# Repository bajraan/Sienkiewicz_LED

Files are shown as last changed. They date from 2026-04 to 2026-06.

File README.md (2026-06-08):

<p align="center" width="100%">
  
</p>

# Sienkiewicz PCB

Sienkiewicz PCB project realized in KiCAD 9

> 🔗 Project main system repository: https://github.com/bajraan/Sienkiewicz__3ART00__SYSTEM

<h1 align="center">3ART13 LED</h1>

<p align="center" width="100%">
  <a href="https://github.com/nguyen-v/KDT_Hierarchical_KiBot/actions/workflows/ci.yaml">
    
  </a>
</p>

***

<p align="center">
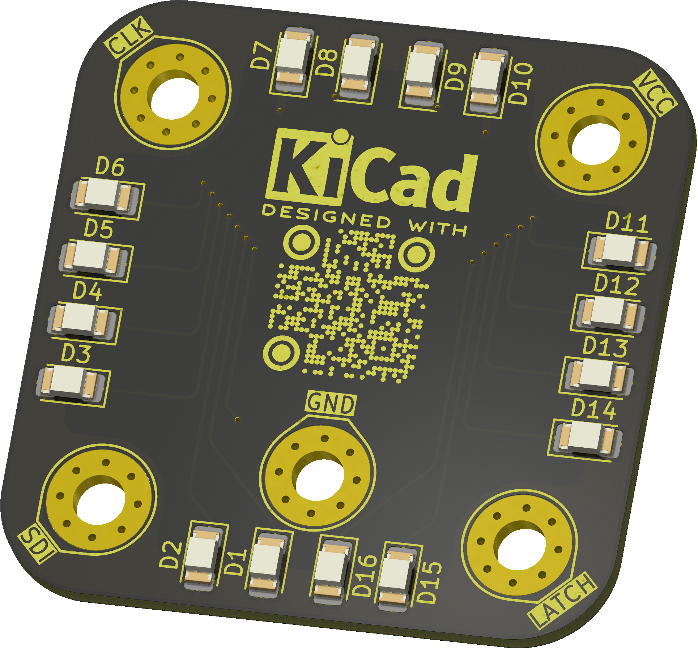
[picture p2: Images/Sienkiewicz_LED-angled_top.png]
3D Top Angled
  
&nbsp; &nbsp; &nbsp; &nbsp;
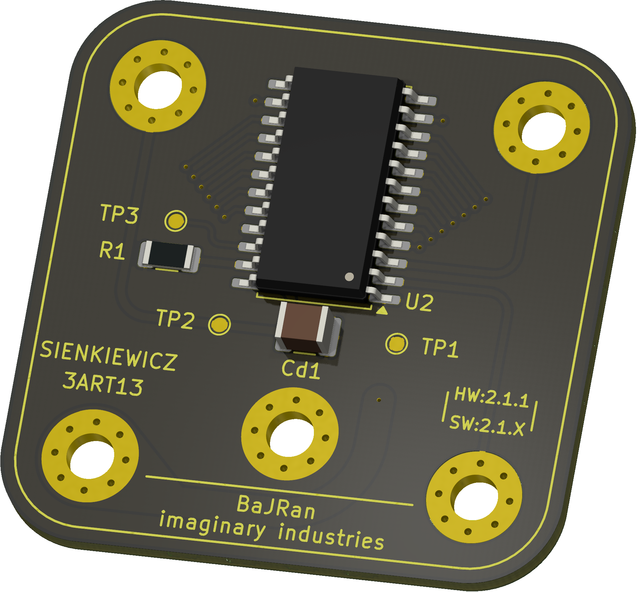
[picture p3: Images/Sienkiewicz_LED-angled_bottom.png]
3D Bottom Angled
  
</p>

***

## SPECIFICATIONS

| Parameter | Value | 
| --- | --- |
| Dimensions | 38.0 × 38.0 mm |

***

## DIRECTORY STRUCTURE

    .
    ├─ Computations       # Misc calculations
    ├─ HTML               # HTML files for generated webpage
    ├─ Images             # Pictures and renders
    │
    ├─ kibot_resources    # External resources for KiBot
    │  ├─ colors          # Color theme for KiCad
    │  ├─ fonts           # Fonts used in the project
    │  ├─ scripts         # External scripts used with KiBot
    │  └─ templates       # Templates for KiBot generated reports
    │
    ├─ kibot_yaml         # KiBot YAML config files
    ├─ KiRI               # KiRI (PCB diff viewer) files
    │
    ├─ lib                # KiCad footprint and symbol libraries
    │  ├─ 3d_models       # Component 3D models
    │  ├─ lib_fp          # Footprint libraries
    │  └─ lib_sym         # Symbol libraries
    │
    ├─ Logos              # Logos
    │
    ├─ Manufacturing      # Assembly and fabrication documents
    │  ├─ Assembly        # Assembly documents (BoM, pos, notes)
    │  │
    │  └─ Fabrication     # Fabrication documents (ZIP, notes)
    │     ├─ Drill Tables # CSV drill tables
    │     └─ Gerbers      # Gerbers
    │
    ├─ Report             # Reports for ERC/DRC
    ├─ Schematic          # PDF of schematic
    ├─ Templates          # Title block templates
    ├─ Testing
    │  └─ Testpoints      # Testpoints tables      
    │
    └─ Variants           # Outputs for assembly variants

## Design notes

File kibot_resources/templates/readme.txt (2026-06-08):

<p align="center" width="100%">
  
</p>

# Sienkiewicz PCB

Sienkiewicz PCB project realized in KiCAD 9

> 🔗 Project main system repository: https://github.com/bajraan/Sienkiewicz__3ART00__SYSTEM

<h1 align="center">${BOARD_NAME}</h1>

<p align="center" width="100%">
  <a href="${GIT_URL}/actions/workflows/ci.yaml">
    CI Badge
  </a>
</p>

***

<p align="center">
  3D Top Angled
&nbsp; &nbsp; &nbsp; &nbsp;
  3D Bottom Angled
</p>

***

## SPECIFICATIONS

| Parameter | Value | 
| --- | --- |
| Dimensions | ${bb_w_mm} × ${bb_h_mm} mm |

***

## DIRECTORY STRUCTURE

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

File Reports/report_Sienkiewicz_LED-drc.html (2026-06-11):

Logo

(https://github.com/INTI-CMNB/KiBot/) | DRC report for Sienkiewicz_LED
| PCB: Sienkiewicz_LED Revision: 2.1.1+ (Unreleased) Date: 2026-06-11T19:33:59+0000 KiCad Version: 9.0.7 | Errors: 0 Warnings: 21 Total: 21

Violations

Type | Description | Details
track_dangling | Track has unconnected end | @(149.975001 mm, 93.0 mm): Track [+5V] on B.Cu (Sig, PWR), length 3.5250 mm
lib_footprint_mismatch | Footprint 'LED_1206_3216Metric' does not match copy in library 'LED_SMD'. | @(146.5 mm, 106.0 mm): Footprint D1
lib_footprint_mismatch | Footprint 'LED_1206_3216Metric' does not match copy in library 'LED_SMD'. | @(142.5 mm, 74.0 mm): Footprint D7
lib_footprint_mismatch | Footprint 'LED_1206_3216Metric' does not match copy in library 'LED_SMD'. | @(154.5 mm, 106.0 mm): Footprint D15
lib_footprint_mismatch | Footprint 'LED_1206_3216Metric' does not match copy in library 'LED_SMD'. | @(132.5 mm, 88.0 mm): Footprint D5
lib_footprint_mismatch | Footprint 'LED_1206_3216Metric' does not match copy in library 'LED_SMD'. | @(150.5 mm, 106.0 mm): Footprint D16
lib_footprint_mismatch | Footprint 'LED_1206_3216Metric' does not match copy in library 'LED_SMD'. | @(132.5 mm, 96.0 mm): Footprint D3
lib_footprint_mismatch | Footprint 'LED_1206_3216Metric' does not match copy in library 'LED_SMD'. | @(154.5 mm, 74.0 mm): Footprint D10
lib_footprint_mismatch | Footprint 'LED_1206_3216Metric' does not match copy in library 'LED_SMD'. | @(142.5 mm, 106.0 mm): Footprint D2
lib_footprint_mismatch | Footprint 'LED_1206_3216Metric' does not match copy in library 'LED_SMD'. | @(164.5 mm, 84.0 mm): Footprint D11
lib_footprint_mismatch | Footprint 'LED_1206_3216Metric' does not match copy in library 'LED_SMD'. | @(146.5 mm, 74.0 mm): Footprint D8
lib_footprint_mismatch | Footprint 'LED_1206_3216Metric' does not match copy in library 'LED_SMD'. | @(164.5 mm, 96.0 mm): Footprint D14
lib_footprint_mismatch | Footprint 'LED_1206_3216Metric' does not match copy in library 'LED_SMD'. | @(164.5 mm, 88.0 mm): Footprint D12
lib_footprint_mismatch | Footprint 'LED_1206_3216Metric' does not match copy in library 'LED_SMD'. | @(150.5 mm, 74.0 mm): Footprint D9
lib_footprint_mismatch | Footprint 'LED_1206_3216Metric' does not match copy in library 'LED_SMD'. | @(132.5 mm, 84.0 mm): Footprint D6
lib_footprint_mismatch | Footprint 'LED_1206_3216Metric' does not match copy in library 'LED_SMD'. | @(132.5 mm, 92.0 mm): Footprint D4
lib_footprint_mismatch | Footprint 'LED_1206_3216Metric' does not match copy in library 'LED_SMD'. | @(164.5 mm, 92.0 mm): Footprint D13
lib_footprint_mismatch | Footprint 'SOIC-24W_7.5x15.4mm_P1.27mm' does not match copy in library 'Package_SO'. | @(148.5 mm, 83.0 mm): Footprint U2
lib_footprint_mismatch | Footprint 'C_1210_3225Metric' does not match copy in library 'Capacitor_SMD'. | @(148.5 mm, 93.0 mm): Footprint Cd1
lib_footprint_mismatch | Footprint 'R_1206_3216Metric' does not match copy in library 'Resistor_SMD'. | @(158.66 mm, 88.715 mm): Footprint R1

Schematic parity

Type | Description | Details
extra_footprint | Extra footprint | @(148.5 mm, 81.0 mm): Footprint REF**

Generated by KiBot (https://github.com/INTI-CMNB/KiBot/) v1.9.1

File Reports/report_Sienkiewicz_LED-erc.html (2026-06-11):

Logo

(https://github.com/INTI-CMNB/KiBot/) | ERC report for Sienkiewicz_LED
| Schematic: Sienkiewicz_LED Revision: 2.1.1+ (Unreleased) Date: 2026-06-11T19:33:57+0000 KiCad Version: 9.0.7 | Errors: 0 Warnings: 18 Total: 18

Sheet / (Sienkiewicz_LED.kicad_sch)

Type | Description | Details
footprint_link_issues | The current configuration does not include the footprint library '__Sienkiewicz'. | @(1.6002 mm, 0.7112 mm): Symbol U1 [Sienkiewicz]
lib_symbol_issues | The current configuration does not include the symbol library '__Sienkiewicz' | @(1.6002 mm, 0.7112 mm): Symbol U1 [Sienkiewicz]
lib_symbol_mismatch | Symbol 'LED_Small' doesn't match copy in library 'Device' | @(1.524 mm, 0.7112 mm): Symbol D1 [LED_Small]
lib_symbol_mismatch | Symbol 'LED_Small' doesn't match copy in library 'Device' | @(1.524 mm, 0.7366 mm): Symbol D2 [LED_Small]
lib_symbol_mismatch | Symbol 'LED_Small' doesn't match copy in library 'Device' | @(1.524 mm, 0.762 mm): Symbol D3 [LED_Small]
lib_symbol_mismatch | Symbol 'LED_Small' doesn't match copy in library 'Device' | @(1.524 mm, 0.7874 mm): Symbol D4 [LED_Small]
lib_symbol_mismatch | Symbol 'LED_Small' doesn't match copy in library 'Device' | @(1.524 mm, 0.8128 mm): Symbol D5 [LED_Small]
lib_symbol_mismatch | Symbol 'LED_Small' doesn't match copy in library 'Device' | @(1.524 mm, 0.8382 mm): Symbol D6 [LED_Small]
lib_symbol_mismatch | Symbol 'LED_Small' doesn't match copy in library 'Device' | @(1.524 mm, 0.8636 mm): Symbol D7 [LED_Small]
lib_symbol_mismatch | Symbol 'LED_Small' doesn't match copy in library 'Device' | @(1.524 mm, 0.889 mm): Symbol D8 [LED_Small]
lib_symbol_mismatch | Symbol 'LED_Small' doesn't match copy in library 'Device' | @(1.524 mm, 0.9144 mm): Symbol D9 [LED_Small]
lib_symbol_mismatch | Symbol 'LED_Small' doesn't match copy in library 'Device' | @(1.524 mm, 0.9398 mm): Symbol D10 [LED_Small]
lib_symbol_mismatch | Symbol 'LED_Small' doesn't match copy in library 'Device' | @(1.524 mm, 0.9652 mm): Symbol D11 [LED_Small]
lib_symbol_mismatch | Symbol 'LED_Small' doesn't match copy in library 'Device' | @(1.524 mm, 0.9906 mm): Symbol D12 [LED_Small]
lib_symbol_mismatch | Symbol 'LED_Small' doesn't match copy in library 'Device' | @(1.524 mm, 1.016 mm): Symbol D13 [LED_Small]
lib_symbol_mismatch | Symbol 'LED_Small' doesn't match copy in library 'Device' | @(1.524 mm, 1.0414 mm): Symbol D14 [LED_Small]
lib_symbol_mismatch | Symbol 'LED_Small' doesn't match copy in library 'Device' | @(1.524 mm, 1.0668 mm): Symbol D15 [LED_Small]
lib_symbol_mismatch | Symbol 'LED_Small' doesn't match copy in library 'Device' | @(1.524 mm, 1.0922 mm): Symbol D16 [LED_Small]

Generated by KiBot (https://github.com/INTI-CMNB/KiBot/) v1.9.1

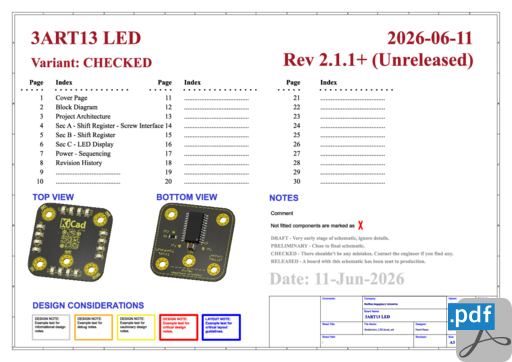
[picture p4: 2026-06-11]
HTML/images/cat_pdf_schematic_Sienkiewicz_LED-schematic.png

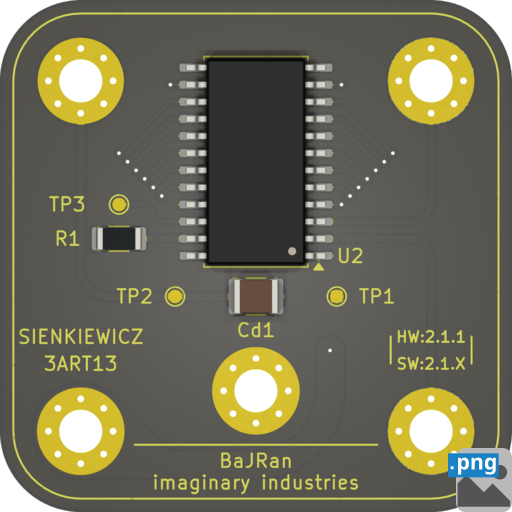
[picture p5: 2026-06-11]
HTML/images/cat_png_3d_viewer_bottom_Sienkiewicz_LED-bottom.png

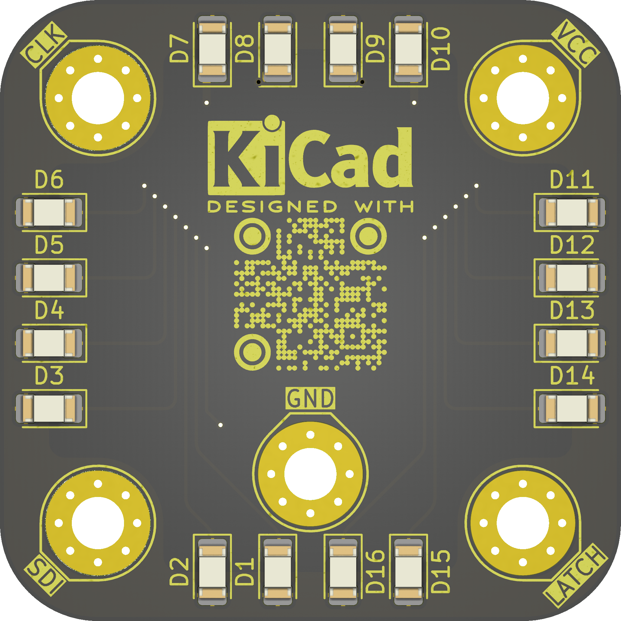
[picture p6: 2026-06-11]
Images/Sienkiewicz_LED-top.png

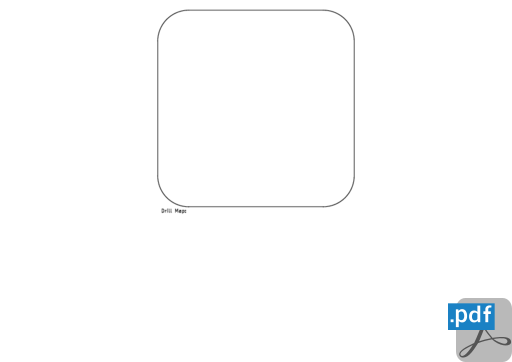
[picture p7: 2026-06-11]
HTML/images/cat_pdf_drill_map_Sienkiewicz_LED-NPTH_drill_map.png

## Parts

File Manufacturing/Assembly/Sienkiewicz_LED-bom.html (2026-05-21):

 | Bill of Materials
 | Schematic: Sienkiewicz_LED Variant: CHECKED Revision: 2.1.1+ (Unreleased) Date: 2025-01-12 KiCad Version: 9.0.7+1 | Component Groups: 5 Component Count: 20 (per PCB) Fitted Components: 20 (per PCB) Number of PCBs: 1 Total Components: 20 (for 1 PCBs)
Row | Quantity Per PCB | References | Value | Datasheet | Footprint | Description | Manufacturer | Manufacturer Part Number | Supplier Part Number
1 | 1 | Cd1 | 100nF | ~ | C_1210_3225Metric | Unpolarized capacitor, small symbol
2 | 16 | D1 D2 D3 D4 D5 D6 D7 D8 D9 D10 D11 D12 D13 D14 D15 D16 | YL | ~ | LED_1206_3216Metric | Light emitting diode, small symbol
3 | 1 | R1 | 1k5 | ~ | R_1206_3216Metric | Resistor, small symbol
4 | 1 | U1 | B-B Interface |  | Sienkiewicz
5 | 1 | U2 | STP16CP05M | https://www.st.com/resource/en/datasheet/stp16cp05.pdf | SOIC-24W_7.5x15.4mm_P1.27mm | 16-bit constant current LED sink driver, 5..100mA output current, 20V driving capability, 3.0..5.5V power supply, SOIC-24
Color reference for columns:
KiCad Fields (default)
Generated Fields
User Fields
Empty Fields

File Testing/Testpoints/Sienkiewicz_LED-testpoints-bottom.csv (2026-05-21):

Ref. | Net | X [mm] | Y [mm]
TP1 | GND | 78.50 | 13.00
TP2 | +5V | 90.50 | 13.00
TP3 | Net-(U2-SDO) | 94.66 | 19.82

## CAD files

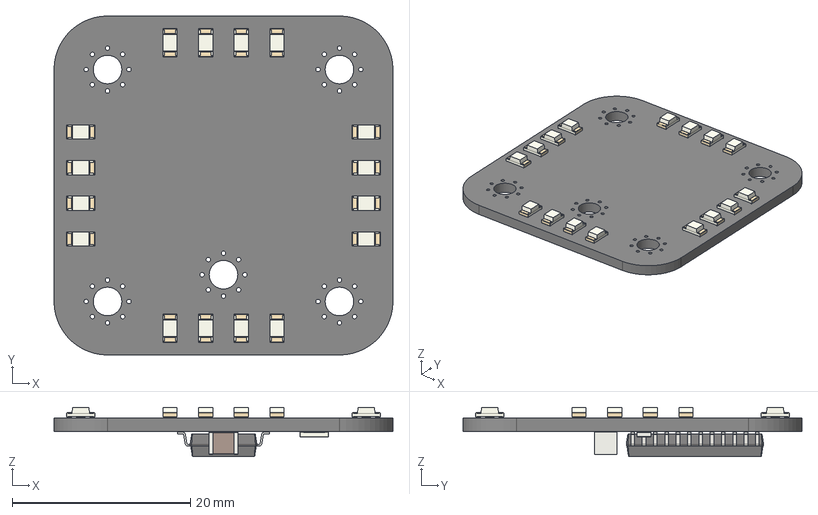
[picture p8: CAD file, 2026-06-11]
3D/Sienkiewicz_LED.step
38.0 x 38.0 x 5.52 mm
LED_1206_3216Metric x 16
SOIC-24W_7.5x15.4mm_P1.27mm
C_1210_3225Metric
R_1206_3216Metric
kibot_dib91y2s_PCB

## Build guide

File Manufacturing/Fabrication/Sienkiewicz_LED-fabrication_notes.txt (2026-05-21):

FABRICATION NOTES (UNLESS OTHERWISE SPECIFIED)

1)	FABRICATE PER IPC-6012A CLASS 2.

2)	OUTLINE DEFINED IN SEPARATE GERBER FILE WITH
	"Edge_Cuts.GBR" SUFFIX.

	DIMENSIONS OF CIRCUMSIZED RECTANGLE SHOWN ON THIS
	DRAWING FOR REFERENCE ONLY.

3)	SEE SEPARATE DRILL FILES WITH ".DRL" SUFFIX 
	FOR HOLE LOCATIONS.

	SELECTED HOLE LOCATIONS SHOWN ON THIS DRAWING 
	FOR REFERENCE ONLY.

4)	SURFACE FINISH: IMMERSION GOLD

5)	SOLDERMASK ON BOTH SIDES OF THE BOARD SHALL 
	BE LPI, COLOR BLACK.

6)	SILK SCREEN LEGEND TO BE APPLIED PER LAYER 
	STACKUP USING YELLOW NON-CONDUCTIVE EPOXY INK.

7)	ALL VIAS ARE TENTED ON BOTH SIDES UNLESS 
	SOLDERMASK OPENED IN GERBER.

8)	VENDOR SHOULD FOLLOW ROHS COMPLIANT PROCESS 
	AND Pb FREE FOR MANUFACTURING

9)	PCB MATERIAL REQUIREMENTS:

	A.	FLAMMABILITY RATING MUST MEET OR EXCEED 
		UL94V-0 REQUIREMENTS.
	B.	Tg 170 C OR EQUIVALENT.
	C.	EQUIVALENT MATERIAL SHALL BE RoHS COMPLIANT, 
		HALOGEN FREE AND APPROVED BY BAJRAN IMGAGINARY INDUSTRIES.

10)	DESIGN GEOMETRY MINIMUM FEATURE SIZES:

	BOARD SIZE				38.000 × 38.000 mm
	BOARD THICKNESS		1.610 mm
	TRACE WIDTH			0.200 mm
	TRACE TO TRACE		0.200 mm
	MIN. HOLE (PTH)			0.250 mm
	MIN. HOLE (NPTH)		N/A mm
	ANNULAR RING			0.150 mm
	COPPER TO HOLE		0.254 mm
	COPPER TO EDGE		0.250 mm
	HOLE TO HOLE			0.254 mm

11)	REFER TO IMPEDANCE TABLE FOR IMPEDANCE CONTROL REQUIREMENTS.

12)	CONFIRM SPACE WIDTHS AND SPACINGS.

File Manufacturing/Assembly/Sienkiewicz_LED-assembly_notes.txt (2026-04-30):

ASSEMBLY NOTES (UNLESS OTHERWISE SPECIFIED)

1)	DO NOT POPULATE PARTS ARE MARKED WITH A RED CROSS.

2)	DO NOT POPULATE PARTS ARE NOT PRESENT IN THE BOM.

3)	IF CONFLICTING INFORMATION IS FOUND BETWEEN THE ASSEMBLY
	FILE AND BOM, BOM SHOULD BE USED AS THE MAIN SOURCE.

4)	CONFORMAL COATING IS NOT REQUIRED.

5)	DOT IDENTIFIES PIN #1 LOCATION AND DEVICE ORIENTATION
	WHEN VIEWED FROM THE TOP.

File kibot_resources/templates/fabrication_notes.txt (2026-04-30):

FABRICATION NOTES (UNLESS OTHERWISE SPECIFIED)

1)	FABRICATE PER IPC-6012A CLASS 2.

2)	OUTLINE DEFINED IN SEPARATE GERBER FILE WITH
	"Edge_Cuts.GBR" SUFFIX.

	DIMENSIONS OF CIRCUMSIZED RECTANGLE SHOWN ON THIS
	DRAWING FOR REFERENCE ONLY.

3)	SEE SEPARATE DRILL FILES WITH ".DRL" SUFFIX 
	FOR HOLE LOCATIONS.

	SELECTED HOLE LOCATIONS SHOWN ON THIS DRAWING 
	FOR REFERENCE ONLY.

4)	SURFACE FINISH: ${pcb_finish_cap}

5)	SOLDERMASK ON BOTH SIDES OF THE BOARD SHALL 
	BE LPI, COLOR ${solder_mask_color_text_cap}.

6)	SILK SCREEN LEGEND TO BE APPLIED PER LAYER 
	STACKUP USING ${silk_screen_color_text_cap} NON-CONDUCTIVE EPOXY INK.

7)	ALL VIAS ARE TENTED ON BOTH SIDES UNLESS 
	SOLDERMASK OPENED IN GERBER.

8)	VENDOR SHOULD FOLLOW ROHS COMPLIANT PROCESS 
	AND Pb FREE FOR MANUFACTURING

9)	PCB MATERIAL REQUIREMENTS:

	A.	FLAMMABILITY RATING MUST MEET OR EXCEED 
		UL94V-0 REQUIREMENTS.
	B.	Tg 170 C OR EQUIVALENT.
	C.	EQUIVALENT MATERIAL SHALL BE RoHS COMPLIANT, 
		HALOGEN FREE AND APPROVED BY ${COMPANY_cap}.

10)	DESIGN GEOMETRY MINIMUM FEATURE SIZES:

	BOARD SIZE				${bb_w_mm} × ${bb_h_mm} mm
	BOARD THICKNESS		${thickness_mm} mm
	TRACE WIDTH			${track_mm} mm
	TRACE TO TRACE		${clearance_mm} mm
	MIN. HOLE (PTH)			${drill_pth_real_mm} mm
	MIN. HOLE (NPTH)		${drill_npth_real_mm} mm
	ANNULAR RING			${oar_mm} mm
	COPPER TO HOLE		${c2h_mm} mm
	COPPER TO EDGE		${c2e_mm} mm
	HOLE TO HOLE			${h2h_mm} mm
#?stackup and impedance_controlled

#?stackup and impedance_controlled
11)	REFER TO IMPEDANCE TABLE FOR IMPEDANCE CONTROL REQUIREMENTS.
#?stackup and impedance_controlled

#?stackup and impedance_controlled
12)	CONFIRM SPACE WIDTHS AND SPACINGS.

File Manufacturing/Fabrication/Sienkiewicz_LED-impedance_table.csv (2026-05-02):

Transmission Line | Impedance [ohms] | Tolerance [ohms] | Layer | Trace Width [mm] | Gap [mm] | Ref. Layers
Edge-Coupled Coated Microstrip | 100 | ±10 % | L1 | 0.2032 | 0.28 | L2

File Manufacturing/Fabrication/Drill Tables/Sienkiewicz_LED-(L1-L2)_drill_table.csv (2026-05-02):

Count | Hole Size | Plated | Hole Shape | Drill Layer Pair | Hole Type
18 | 0.25mm (9.84mils) | PTH | Round | T.Cu (Sig, PWR) - B.Cu (Sig, PWR) | Via
40 | 0.50mm (19.69mils) | PTH | Round | T.Cu (Sig, PWR) - B.Cu (Sig, PWR) | Pad
5 | 3.20mm (125.98mils) | PTH | Round | T.Cu (Sig, PWR) - B.Cu (Sig, PWR) | Pad
Total 63

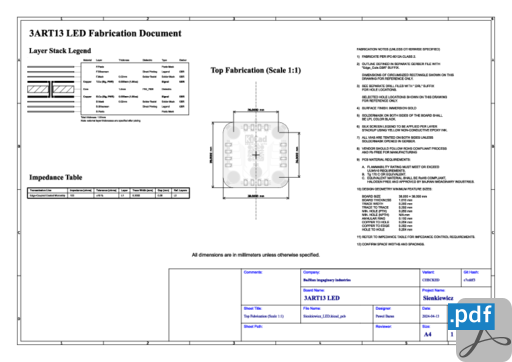
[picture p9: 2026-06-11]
HTML/images/cat_pdf_fabrication_Sienkiewicz_LED-fabrication.png

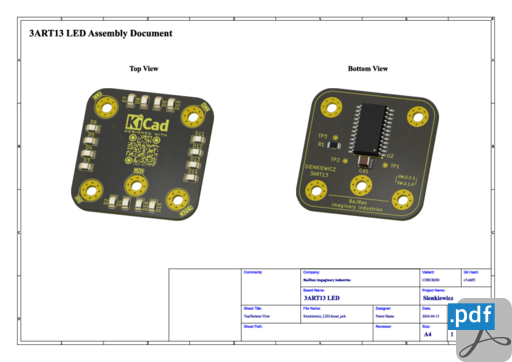
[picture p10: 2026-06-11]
HTML/images/cat_pdf_assembly_Sienkiewicz_LED-assembly.png

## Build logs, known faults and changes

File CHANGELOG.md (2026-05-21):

# Changelog

## [Unreleased]

## [2.1.1] - 2026-05-21

## [2.1.1] - 2026-05-21

### Changed

-   B-B connector maping changes restored

### Added

-   requirements section added for documentation

## [2.1.0] - 2026-05-02

### Added

-   First version of PCB and Schematic

[Unreleased]: https://github.com/bajraan/Sienkiewicz_LED/compare/2.1.1...HEAD

[2.1.1]: https://github.com/bajraan/Sienkiewicz_LED/compare/2.1.1...2.1.1

[2.1.1]: https://github.com/bajraan/Sienkiewicz_LED/compare/2.1.0...2.1.1

[2.1.0]: https://github.com/bajraan/Sienkiewicz_LED/compare/fb442570a65d27a13fec5e740bfc5e15bcf4bb85...2.1.0

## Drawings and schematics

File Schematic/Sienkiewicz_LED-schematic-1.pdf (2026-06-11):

2026-06-11

# 3ART13LED

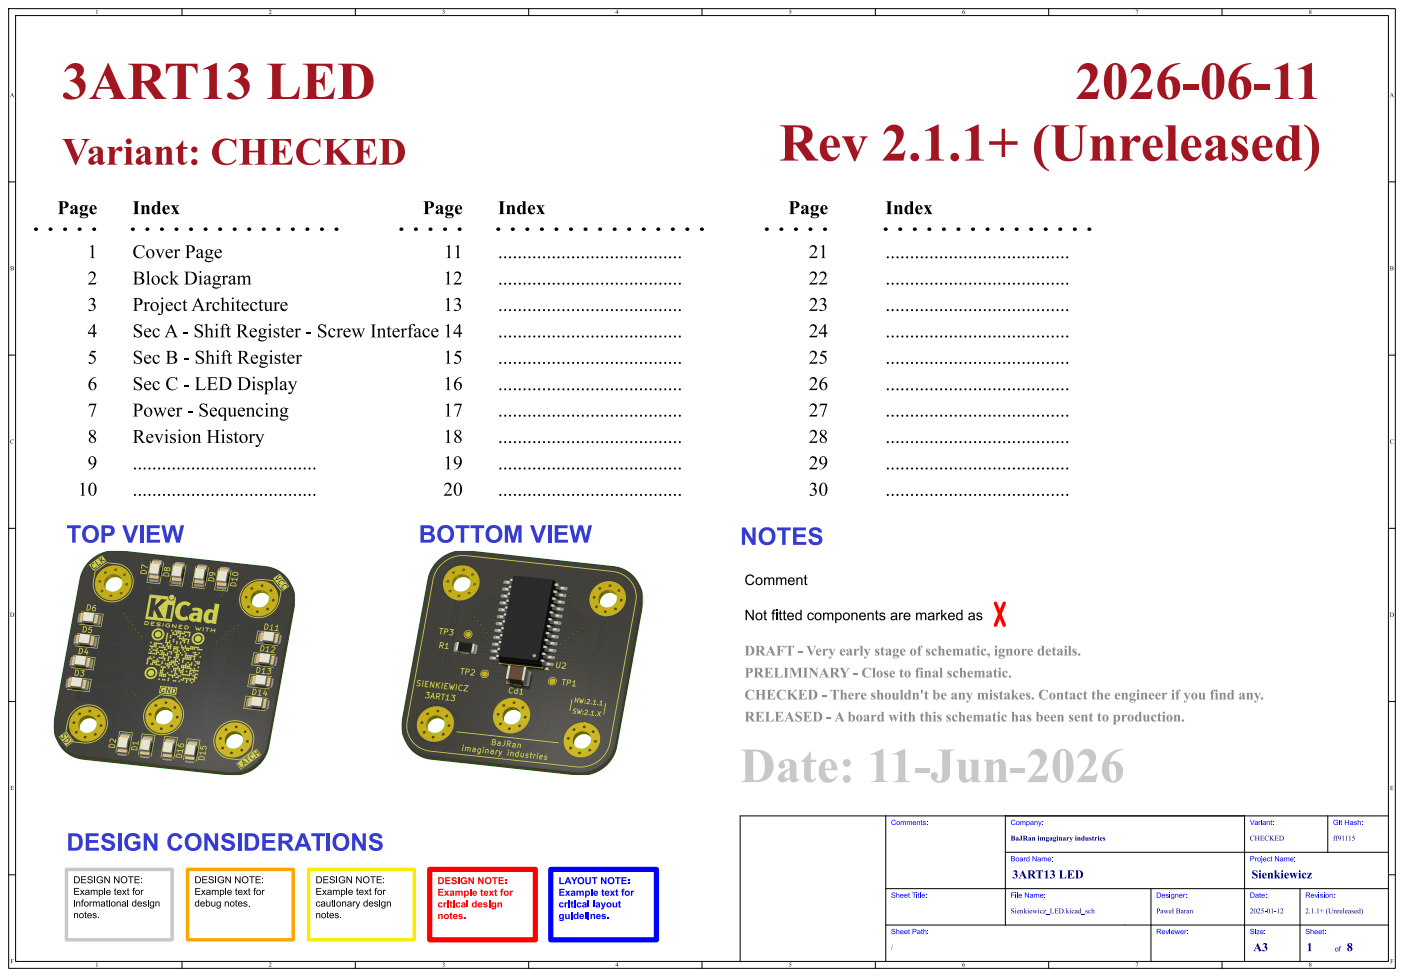
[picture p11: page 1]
Sheet: of 8; Size: A3; Sienkiewicz_LED.kicad_sch; þÿPaweB Baran Board Name:; Variant: CHECKED; Company: BaJRanimgaginaryindustries 3ART13LED; Sienkiewicz; Sheet Title:; File Name:; /Sheet Path: Comments:; Git Hash:; ff91115 ProjectArchitecture; kibot_image_png_3d_viewer_angled_top; kibot_image_png_3d_viewer_angled_bottom; LAYOUT NOTE:; DESIGN CONSIDERATIONS; TOP VIEW; ...................................... Comment; RELEASED - A boardwiththisschematichasbeensenttoproduction.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

SecA - Shift Register- ScrewInterface
SecB - Shift Register
SecC - LED Display
...................................... Power- Sequencing
RevisionHistory

CHECKED - Thereshouldn'tbeanymistakes.Contacttheengineerif youfindany. ......................................

Not fitted components are marked as

DRAFT - Veryearlystageof schematic,ignoredetails.
PRELIMINARY - Closetofinal schematic.
Date:11-Jun-2026

Revision: 2.1.1+(Unreleased) Date: Project Name: 2025-01-12 Reviewer: Designer:

DESIGN NOTE:
Example text for
informational design
notes.

debug notes.

cautionary design

critical design

critical layout
guidelines.

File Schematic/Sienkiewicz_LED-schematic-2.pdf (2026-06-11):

# CONNECTOR

## Page5

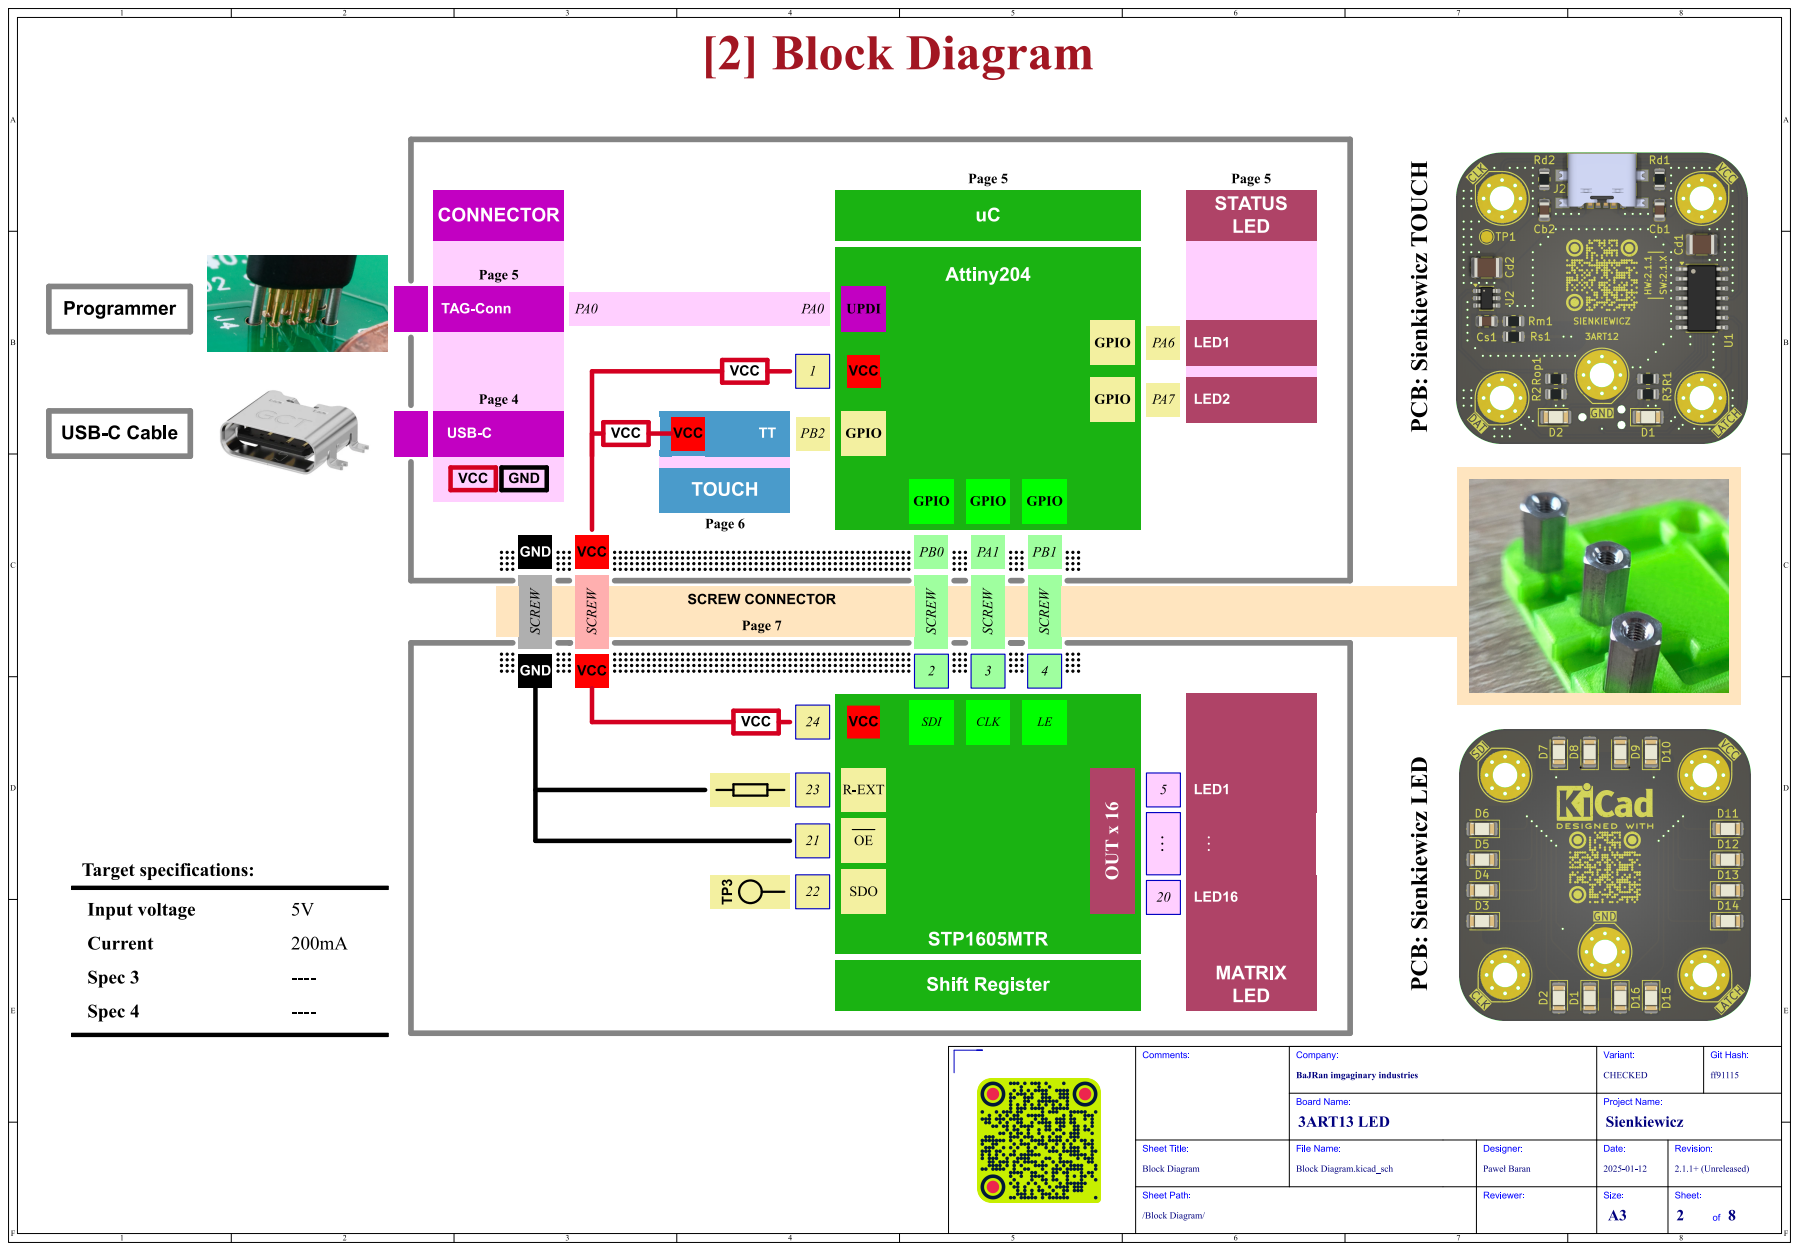
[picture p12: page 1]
Sheet: of 8; Size: A3; Revision: 2.1.1+(Unreleased) Date: Project Name: 2025-01-12 Reviewer: Designer: Block Diagram.kicad_sch; þÿPaweB Baran Board Name:; Variant: CHECKED; Company: BaJRanimgaginaryindustries 3ART13LED; Sienkiewicz; Sheet Title:; File Name:; Comments:; Git Hash:; ff91115 SCREW; GPIO; Page4; USB-C; VCC; GND; [2] BlockDiagram; LED16; LED1; . . . 2 SCREW; SDI; CLK; LE SCREW; SCREW; SDO; OUT; R-EXT; ---- USB-C Cable; TP³; Page5; TAG-Conn; STP1605MTR; Shift Register; Programmer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

/Block Diagram/ Sheet Path: Block Diagram

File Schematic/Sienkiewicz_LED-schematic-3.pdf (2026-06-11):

# [3] ProjectArchitecture

# PCB:SienkiewiczTOUCH

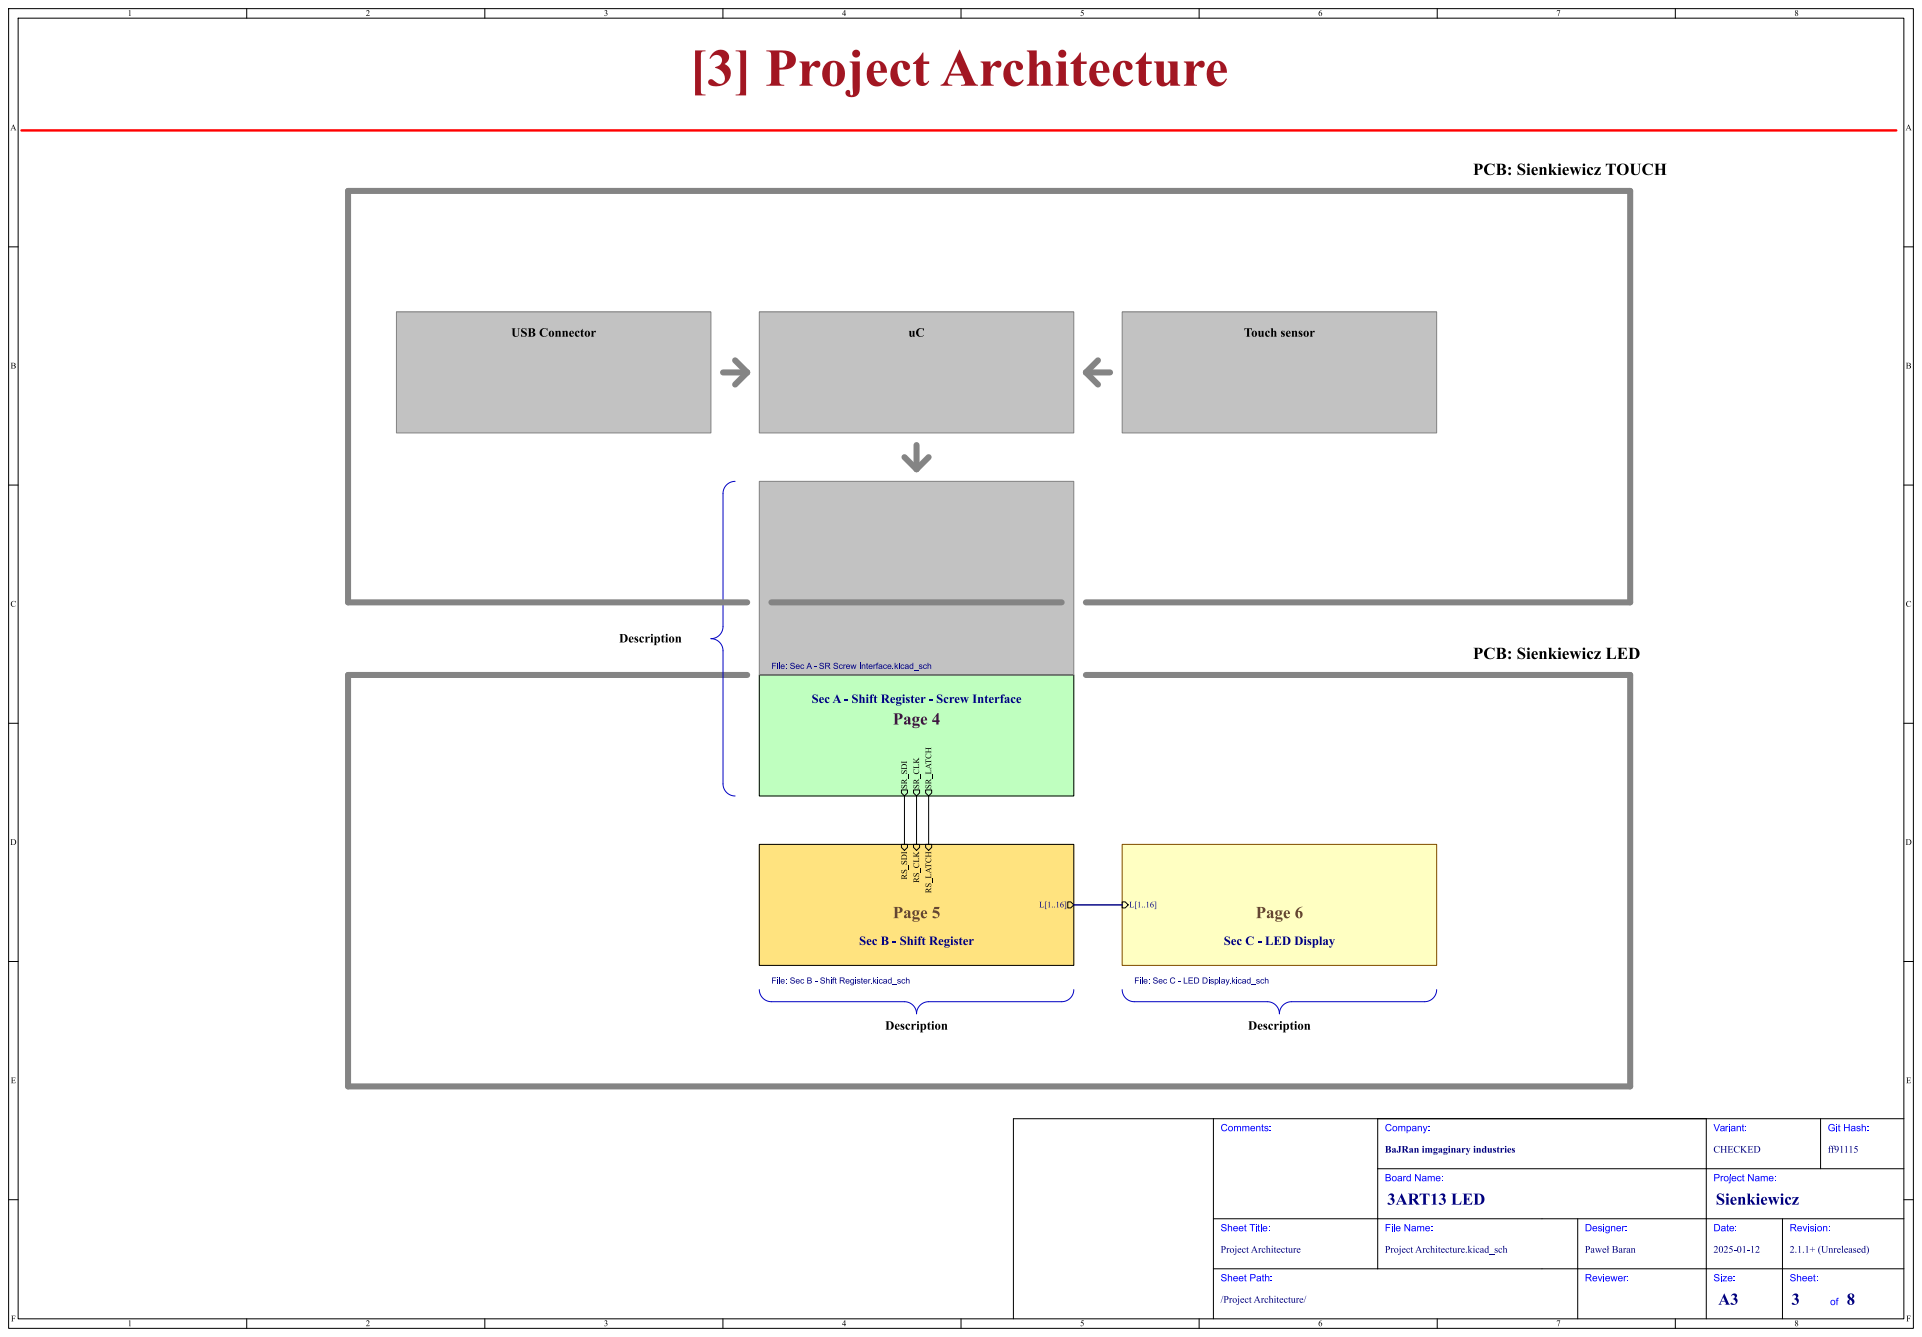
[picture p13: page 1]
Sheet: of 8; Size: A3; ProjectArchitecture.kicad_sch; þÿPaweB Baran Board Name:; Variant: CHECKED; Company: BaJRanimgaginaryindustries 3ART13LED; Sienkiewicz; Sheet Title:; File Name:; /ProjectArchitecture/ Sheet Path: ProjectArchitecture Comments:; Git Hash:; Description; Page5; Page6; Page4; USBConnector; Touchsensor; PCB:SienkiewiczLED

File: Sec A - SR Screw Interface.kicad_sch RS_CLK RS_LATCH RS_SDI

SecA - ShiftRegister- ScrewInterface

File: Sec C - LED Display.kicad_sch SR_SDI SR_CLK SR_LATCH

SecB - ShiftRegister File: Sec B - Shift Register.kicad_sch

SecC - LED Display

Revision: 2.1.1+(Unreleased) Date: Project Name: 2025-01-12 Reviewer: Designer:

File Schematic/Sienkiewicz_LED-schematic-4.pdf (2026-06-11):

SR_SDI | SR_LATCH [4] Shiftregister- ScrewInterface

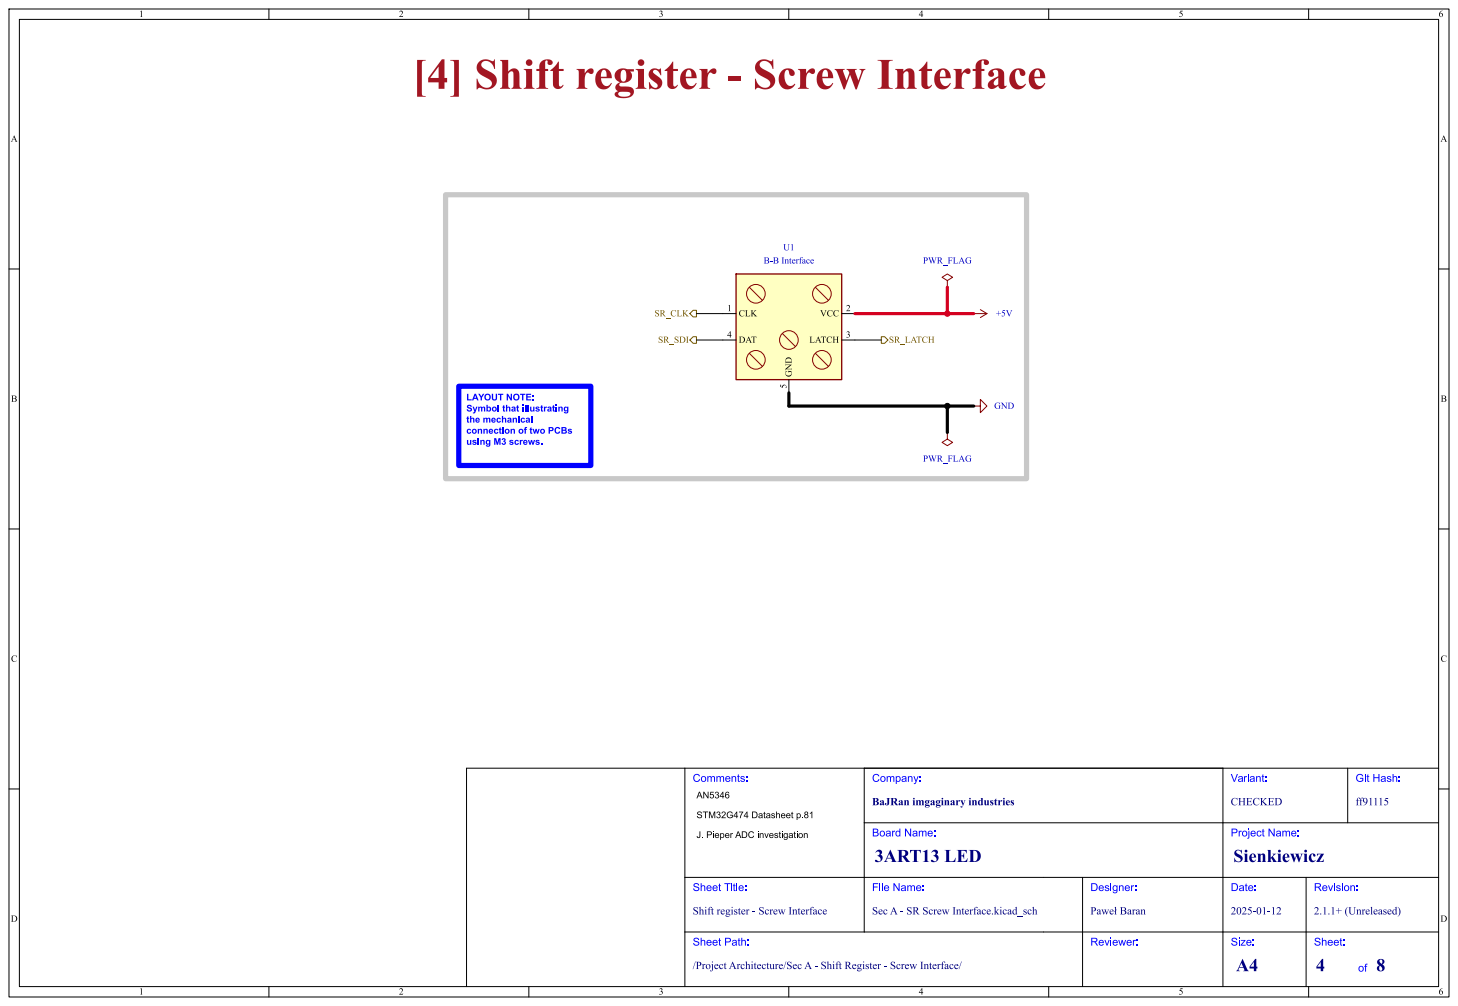
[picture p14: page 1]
Sheet: of 8; Size: A4; Revision: 2.1.1+(Unreleased) Date: Project Name: 2025-01-12 Reviewer: Designer: SecA - SRScrewInterface.kicad_sch; þÿPaweB Baran Board Name:; Variant: CHECKED; Company: BaJRanimgaginaryindustries 3ART13LED; Sienkiewicz; Sheet Title:; File Name:; /ProjectArchitecture/SecA - Shift Register- ScrewInterface/ Sheet Path: Shift register- ScrewInterface Comments:; Git Hash:; +5V GND; PWR_FLAG; CLK 1 DAT 4; GND; 5 VCC 2; LATCH 3 U1 B-B Interface; SR_CLK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

LAYOUT NOTE: Symbol that illustrating

J. Pieper ADC investigation (https://jpieper.com/2023/07/24/stm32g4-adc-performance-part-2/) STM32G474 Datasheet p.81

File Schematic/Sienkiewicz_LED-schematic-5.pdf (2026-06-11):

# [5] ShiftRegister

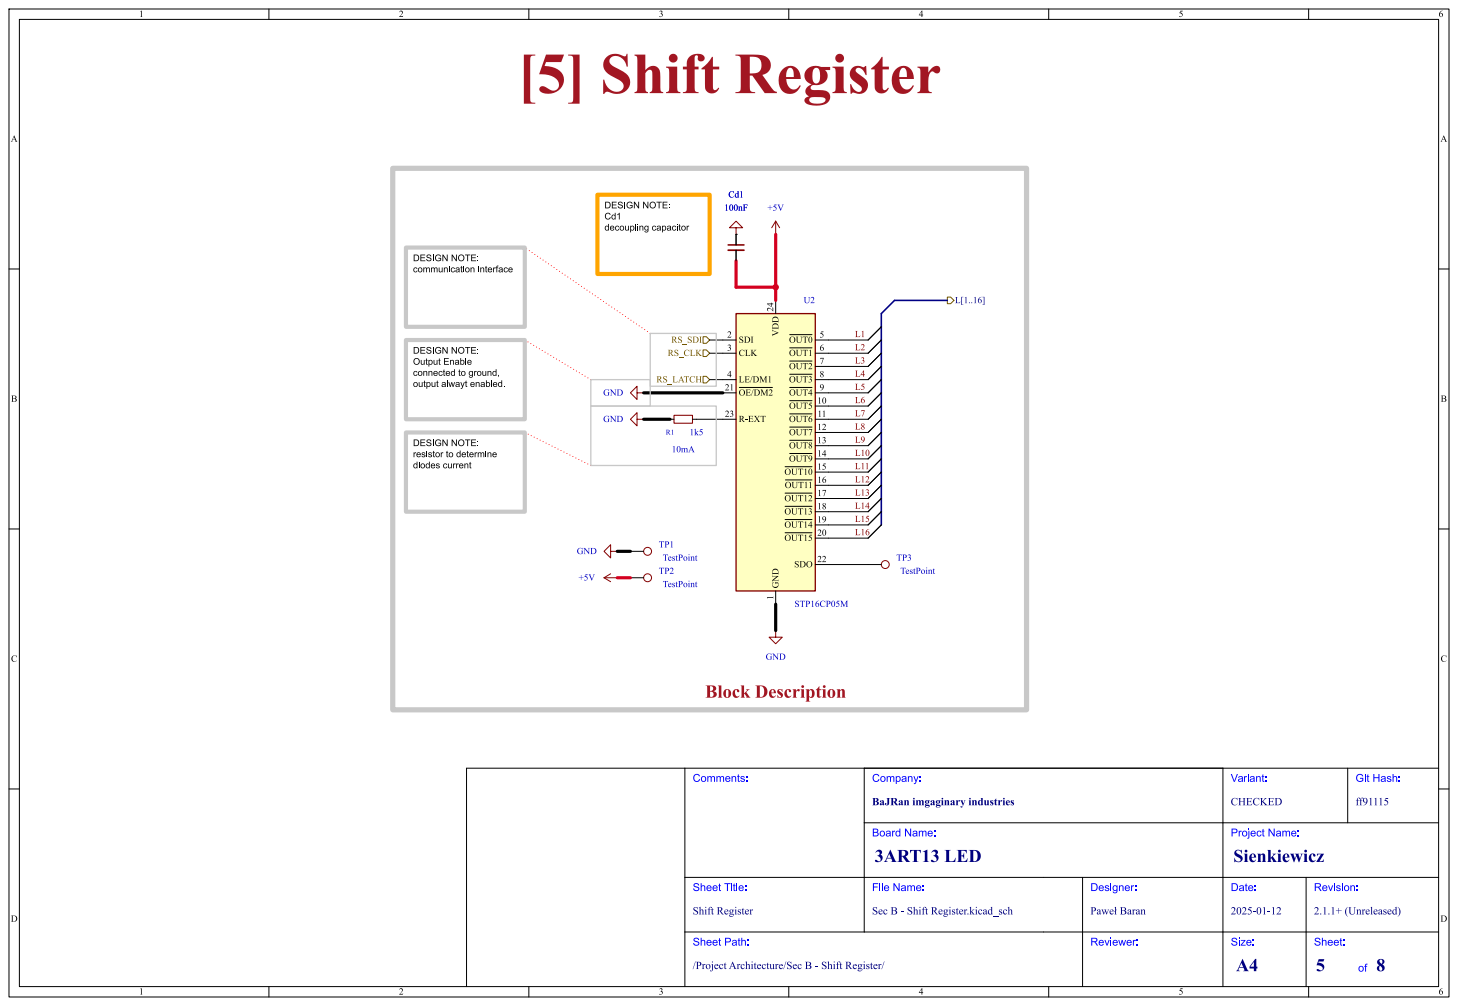
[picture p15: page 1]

DESIGN NOTE: communication interface DESIGN NOTE: resistor to determine

DESIGN NOTE: Output Enable

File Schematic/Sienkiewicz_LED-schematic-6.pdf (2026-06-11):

# [6] LED Display

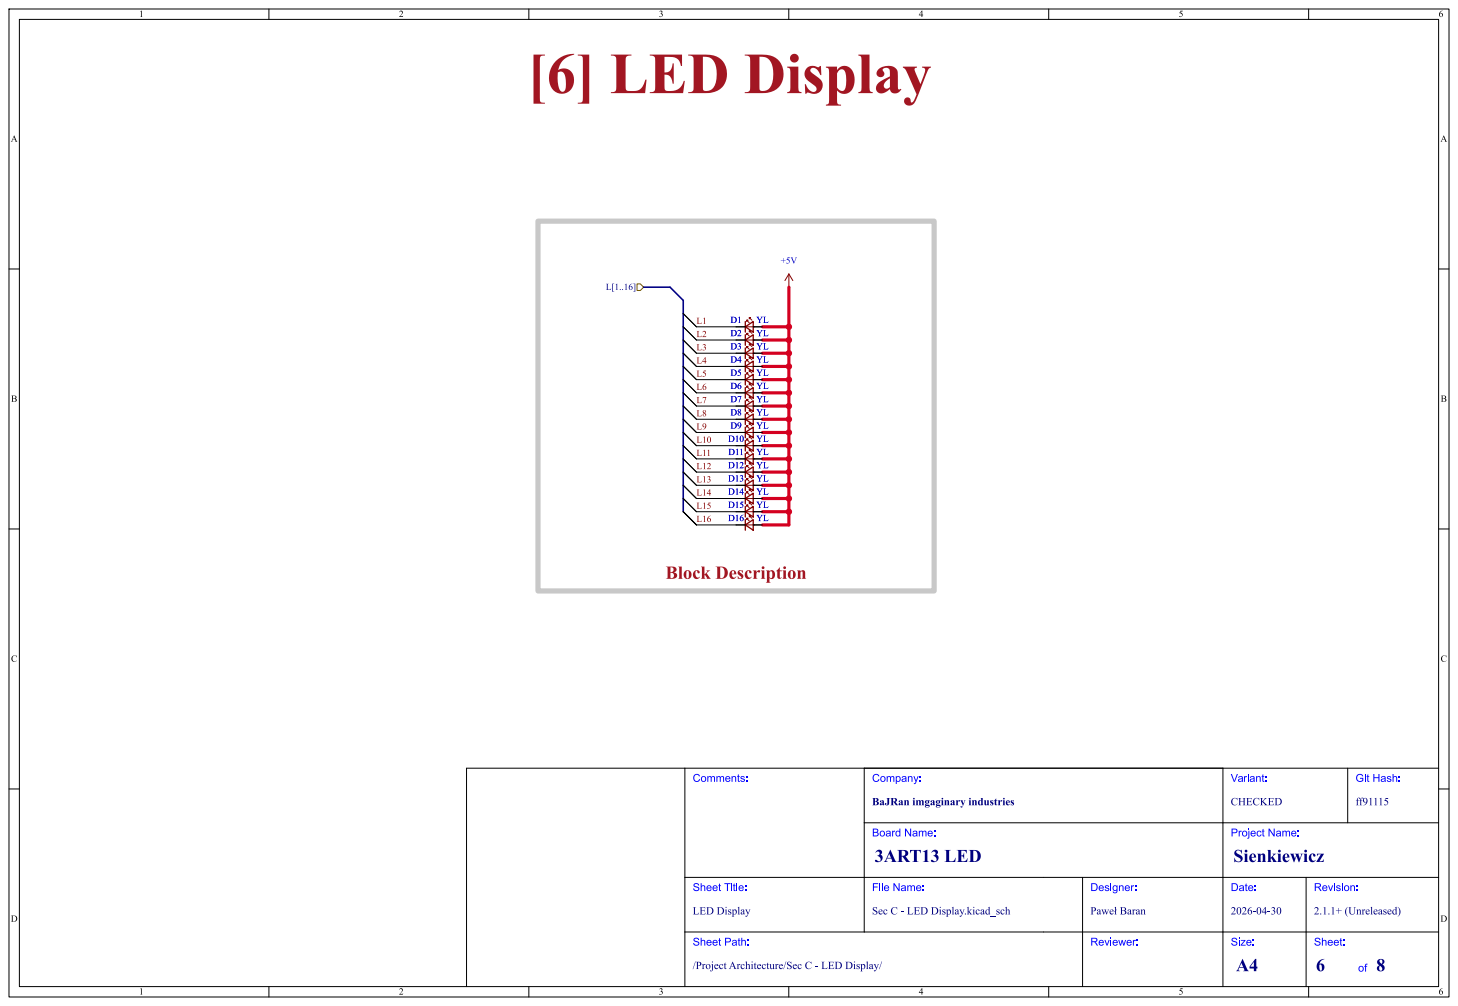
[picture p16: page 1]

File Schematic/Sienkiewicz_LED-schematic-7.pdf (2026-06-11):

## MEET

# [7] Requirements

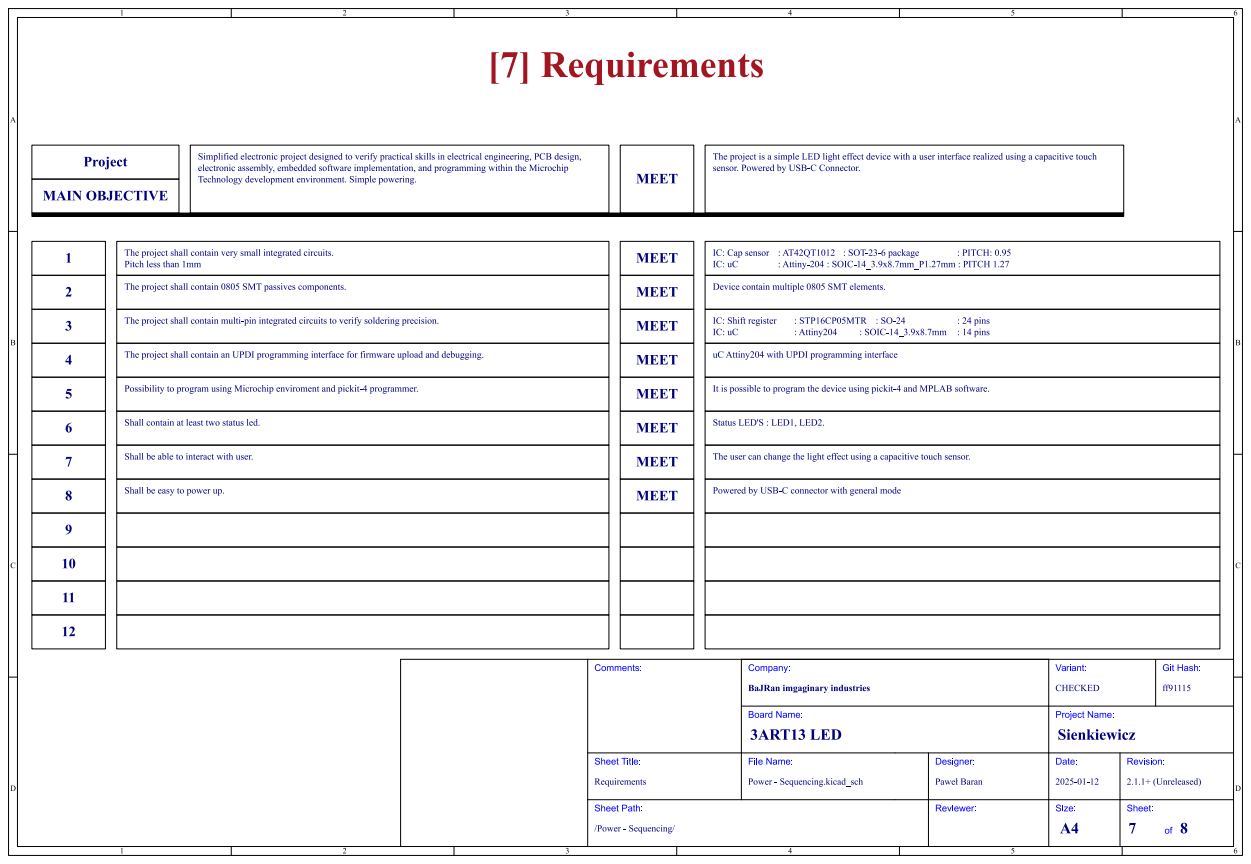
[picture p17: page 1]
Sheet: of 8; Size: A4; Revision: 2.1.1+(Unreleased) Date: Project Name: 2025-01-12 Reviewer: Designer: Power- Sequencing.kicad_sch; þÿPaweB Baran Board Name:; Variant: CHECKED; Company: BaJRanimgaginaryindustries 3ART13LED; Sienkiewicz; Sheet Title:; File Name:; /Power- Sequencing/ Sheet Path: Requirements Comments:; Git Hash:; IC: Capsensor : AT42QT1012 : SOT-23-6package:; PITCH: 0.95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

Simplified electronicprojectdesignedto verify practicalskills in electricalengineering,PCBdesign, electronicassembly,embeddedsoftwareimplementation,andprogrammingwithin theMicrochip

Theprojectis a simpleLED light effectdevicewith a userinterfacerealizedusinga capacitivetouch
sensor.Poweredby USB-CConnector.

Technologydevelopmentenvironment.Simplepowering. Theprojectshallcontain0805SMT passivescomponents. Theprojectshallcontainvery smallintegratedcircuits. Pitchlessthan1mm

ff91115 Devicecontainmultiple 0805SMT elements. MEET
MEET

Theprojectshallcontainmulti-pin integratedcircuitsto verify solderingprecision. 3

It is possibleto programthedeviceusingpickit-4 andMPLAB software. MEET

Shallbeableto interactwith user. Shallbeeasyto powerup. Shallcontainat leasttwo statusled. Possibilityto programusingMicrochip enviromentandpickit-4 programmer. TheprojectshallcontainanUPDI programminginterfacefor firmwareuploadanddebugging.

Theusercanchangethelight effectusinga capacitivetouchsensor. Poweredby USB-Cconnectorwith generalmode

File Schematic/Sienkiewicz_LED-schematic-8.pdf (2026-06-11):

### ___________________________________ Added

### - First version of PCB and Schematic

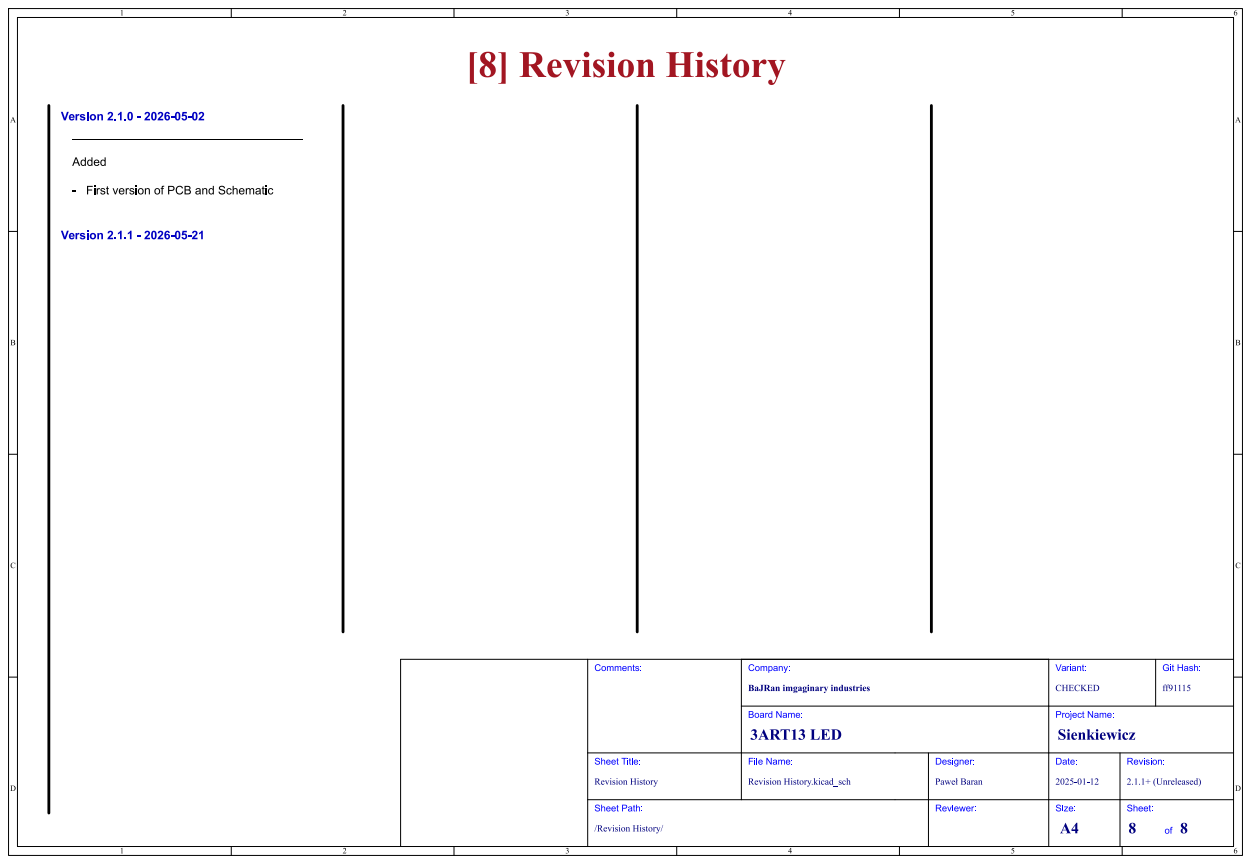
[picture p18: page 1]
Sheet: of 8; Size: A4; Revision: 2.1.1+(Unreleased) Date: Project Name: 2025-01-12 Reviewer: Designer: RevisionHistory.kicad_sch; þÿPaweB Baran Board Name:; Variant: CHECKED; Company: BaJRanimgaginaryindustries 3ART13LED; Sienkiewicz; Sheet Title:; File Name:; /RevisionHistory/ Sheet Path: RevisionHistory Comments:; Git Hash:; ff91115 Version 2.1.1 - 2026-05-21; Version 2.1.0 - 2026-05-02; [8] RevisionHistory

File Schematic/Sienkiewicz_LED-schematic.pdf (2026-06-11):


SecA - Shift Register- ScrewInterface
SecB - Shift Register
SecC - LED Display
...................................... Power- Sequencing
RevisionHistory

CHECKED - Thereshouldn'tbeanymistakes.Contacttheengineerif youfindany. ......................................

Not fitted components are marked as

DRAFT - Veryearlystageof schematic,ignoredetails.
PRELIMINARY - Closetofinal schematic.
Date:11-Jun-2026

Revision: 2.1.1+(Unreleased) Date: Project Name: 2025-01-12 Reviewer: Designer:


/Block Diagram/ Sheet Path: Block Diagram


File: Sec A - SR Screw Interface.kicad_sch RS_CLK RS_LATCH RS_SDI

File: Sec C - LED Display.kicad_sch SR_SDI SR_CLK SR_LATCH

SecB - ShiftRegister File: Sec B - Shift Register.kicad_sch

Revision: 2.1.1+(Unreleased) Date: Project Name: 2025-01-12 Reviewer: Designer:


LAYOUT NOTE: Symbol that illustrating

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


DESIGN NOTE: communication interface DESIGN NOTE: resistor to determine

DESIGN NOTE: Output Enable



Simplified electronicprojectdesignedto verify practicalskills in electricalengineering,PCBdesign, electronicassembly,embeddedsoftwareimplementation,andprogrammingwithin theMicrochip

Theprojectis a simpleLED light effectdevicewith a userinterfacerealizedusinga capacitivetouch
sensor.Poweredby USB-CConnector.

Technologydevelopmentenvironment.Simplepowering. Theprojectshallcontain0805SMT passivescomponents. Theprojectshallcontainvery smallintegratedcircuits. Pitchlessthan1mm

Theprojectshallcontainmulti-pin integratedcircuitsto verify solderingprecision. 3

It is possibleto programthedeviceusingpickit-4 andMPLAB software. MEET

Shallbeableto interactwith user. Shallbeeasyto powerup. Shallcontainat leasttwo statusled. Possibilityto programusingMicrochip enviromentandpickit-4 programmer. TheprojectshallcontainanUPDI programminginterfacefor firmwareuploadanddebugging.

Theusercanchangethelight effectusinga capacitivetouchsensor. Poweredby USB-Cconnectorwith generalmode


- First version of PCB and Schematic

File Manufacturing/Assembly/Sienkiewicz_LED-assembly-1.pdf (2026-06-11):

# 3ART13 LED Assembly Document

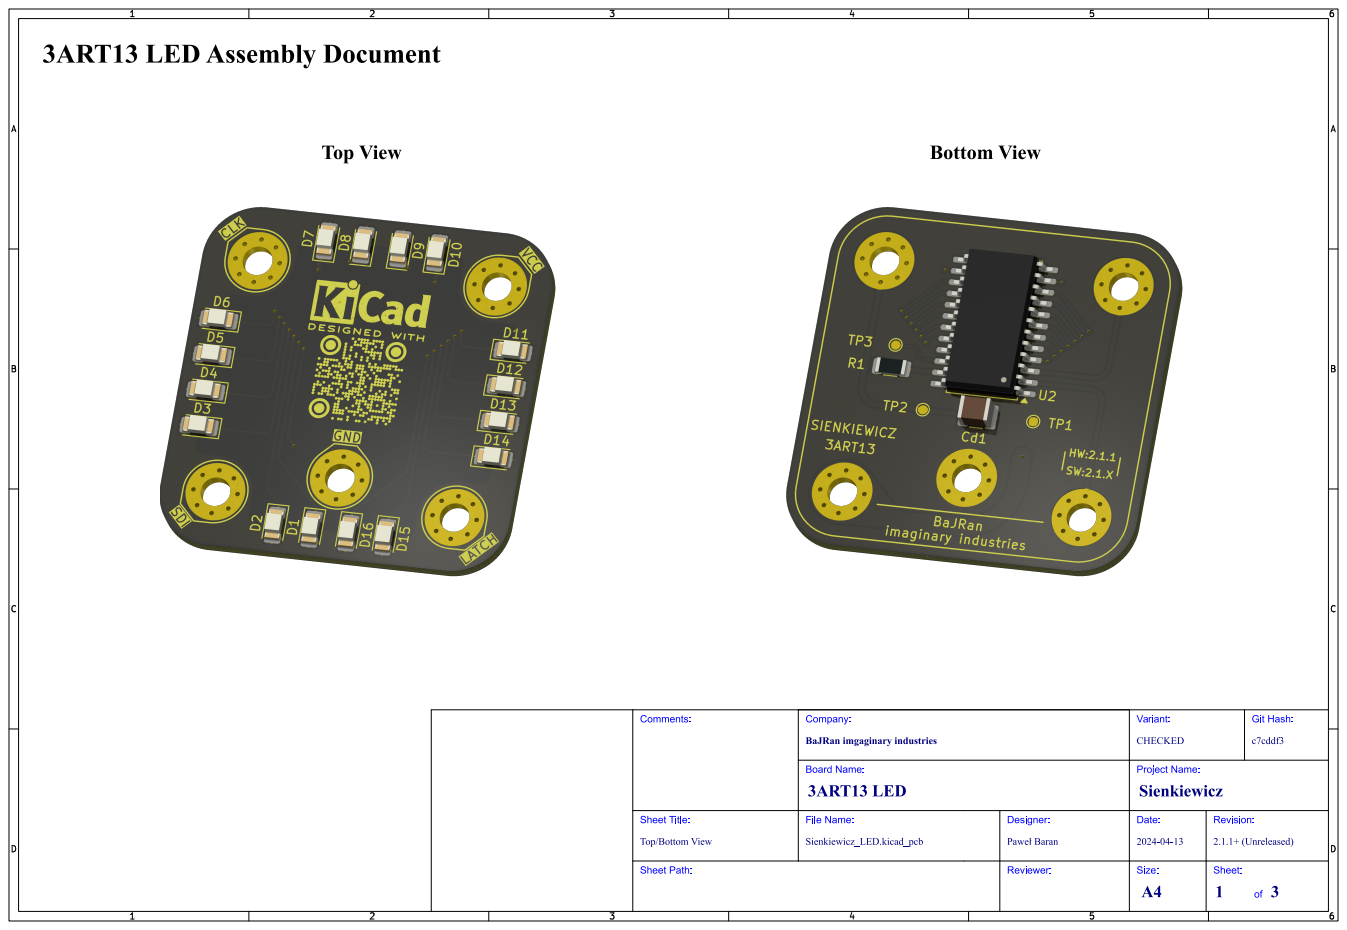
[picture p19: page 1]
Git; Hash:; c7cddf3; Comments:; Sheet Path:; Sheet Title:; File Name:; 3ART13 LED; Sienkiewicz; Company:; CHECKED; Variant:; Board Name:; Sienkiewicz_LED.kicad_pcb; Paweł Baran; Designer:; Reviewer:; Project Name:; Date:; 2.1.1+ (Unreleased); Revision:; Size:; Sheet: 1

BaJRan imgaginary industries

Top/Bottom View

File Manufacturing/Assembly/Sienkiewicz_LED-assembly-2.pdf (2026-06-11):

# Top Assembly (Scale 1:1)

# 3ART13 LED Assembly Document

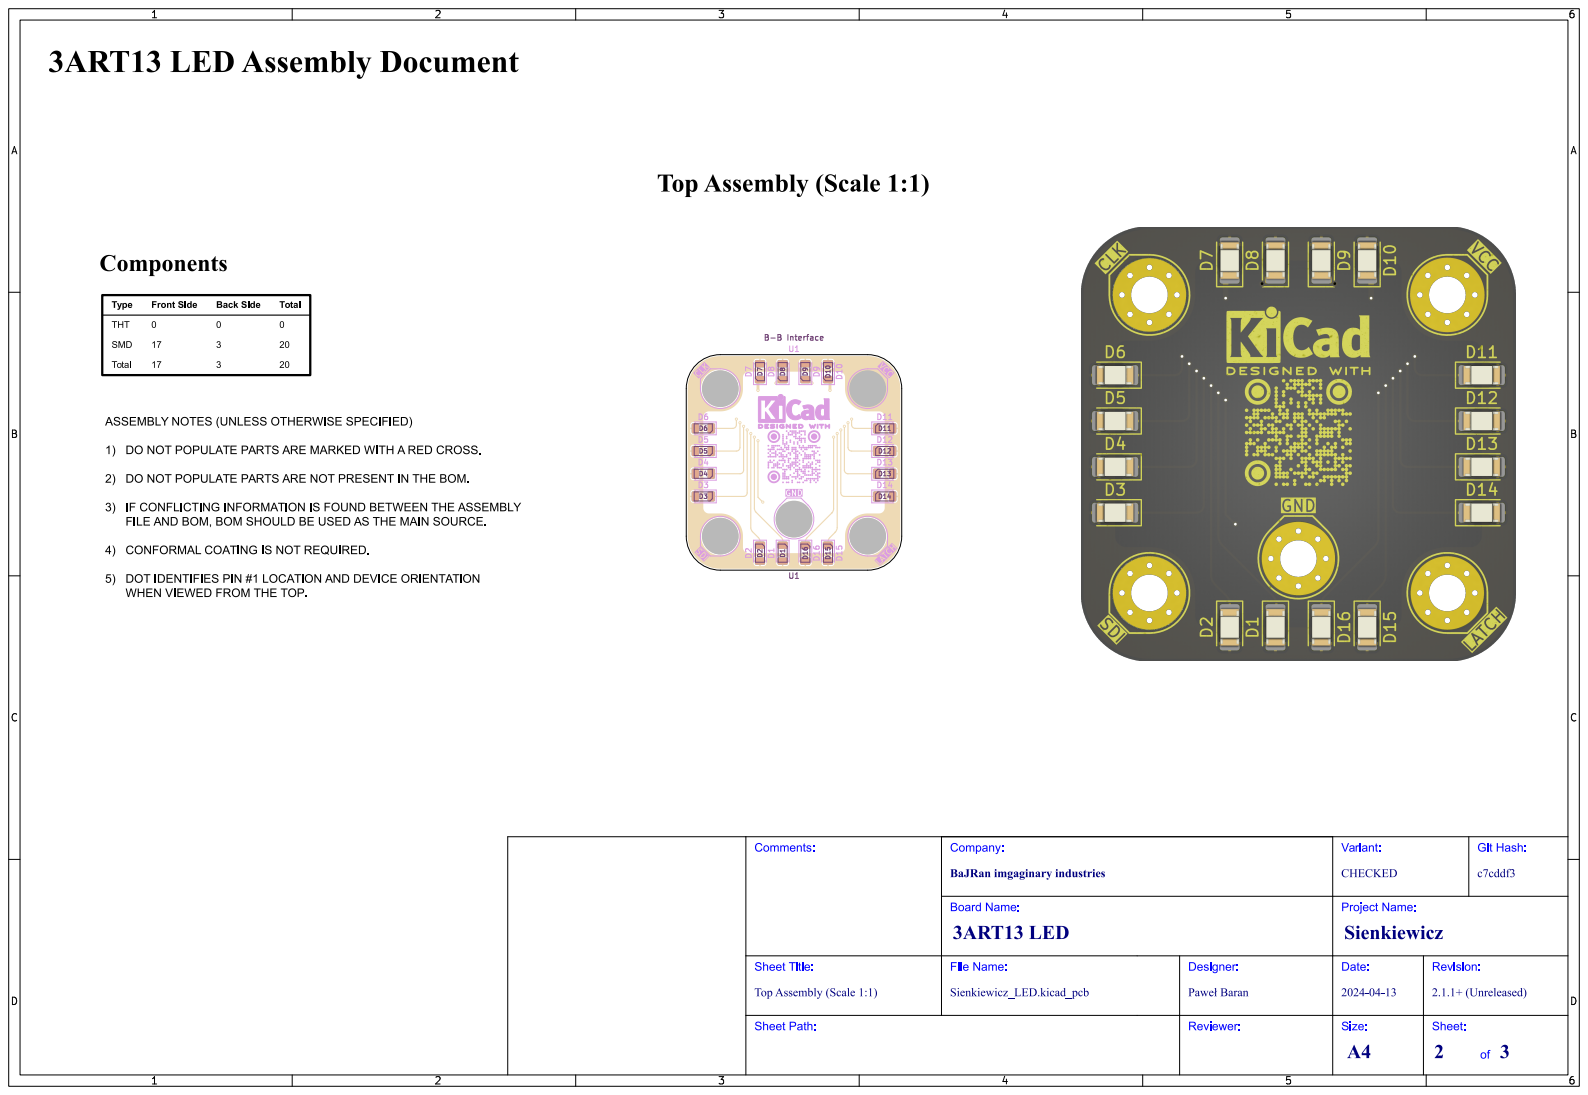
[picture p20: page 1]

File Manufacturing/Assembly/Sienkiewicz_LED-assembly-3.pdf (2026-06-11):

# Bottom Assembly (Scale 1:1)

# 3ART13 LED Assembly Document

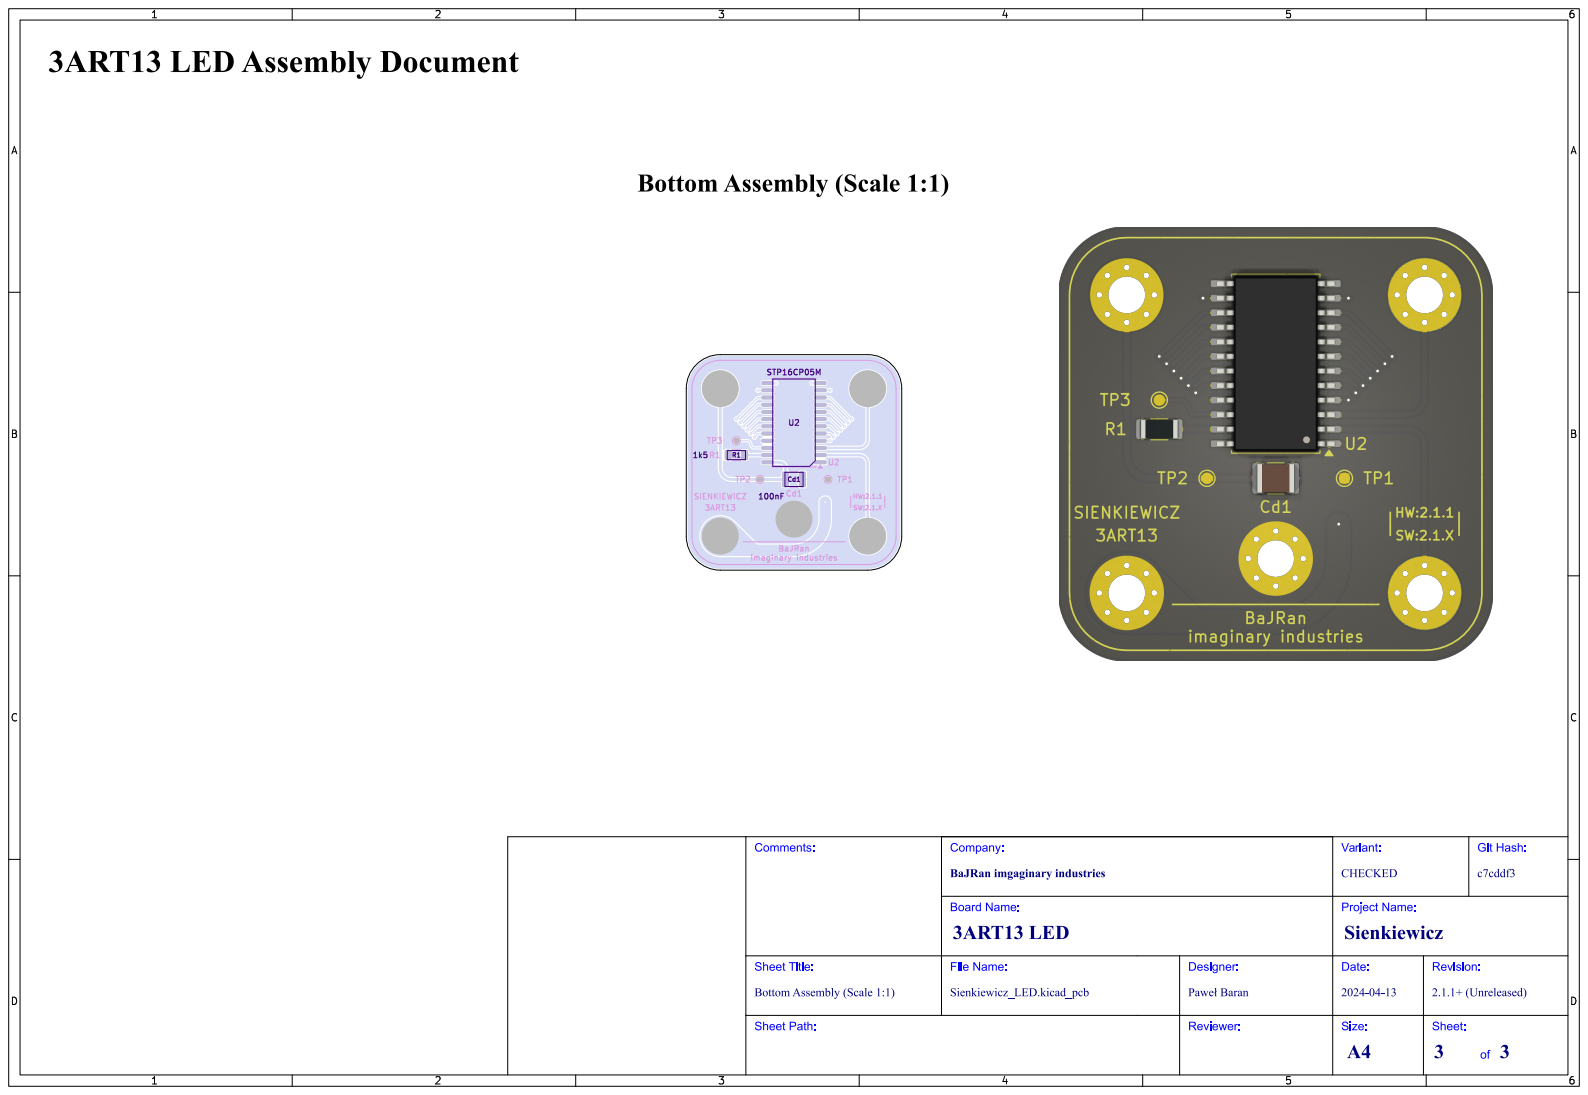
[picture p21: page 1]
Git; Hash:; c7cddf3; Comments:; Sheet Path:; Sheet Title:; File Name:; 3ART13 LED; Sienkiewicz; Company:; CHECKED; Variant:; Board Name:; Sienkiewicz_LED.kicad_pcb; Paweł Baran; Designer:; Reviewer:; Project Name:; Date:; 2.1.1+ (Unreleased); Revision:; Size:; Sheet: 3; STP16CP05M; 3ART13; SIENKIEWICZ; imaginary industries; BaJRan

BaJRan imgaginary industries

Bottom Assembly (Scale 1:1)

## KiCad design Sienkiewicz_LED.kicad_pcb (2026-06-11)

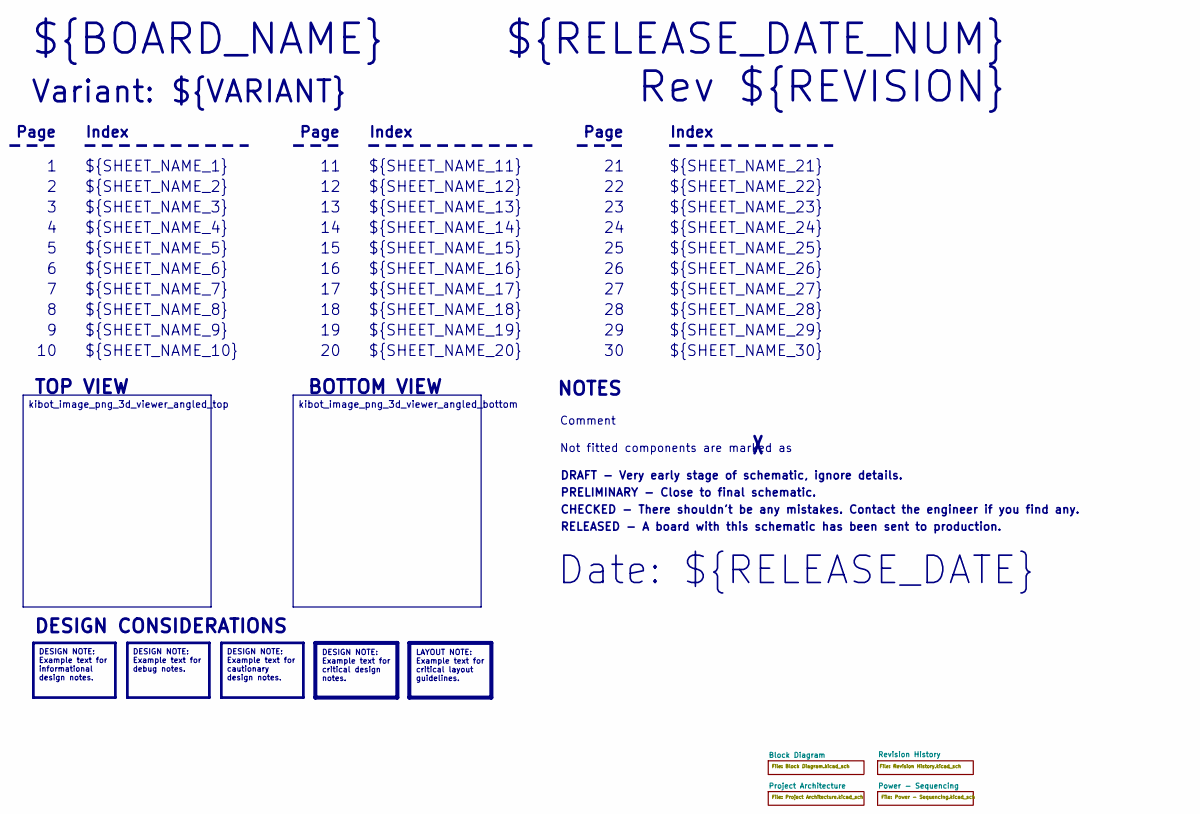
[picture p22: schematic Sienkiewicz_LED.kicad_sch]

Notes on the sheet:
Variant: ${VARIANT}
RELEASED - A board with this schematic has been sent to production.
${SHEET_NAME_24}
Index
PRELIMINARY - Close to final schematic.
${SHEET_NAME_22}
DRAFT - Very early stage of schematic, ignore details.
${SHEET_NAME_12}
${SHEET_NAME_8}
${SHEET_NAME_2}
${SHEET_NAME_5}
${SHEET_NAME_20}
Page
${SHEET_NAME_23}
${RELEASE_DATE_NUM}
Not fitted components are marked as
${SHEET_NAME_11}
${SHEET_NAME_6}
${SHEET_NAME_26}
Rev ${REVISION}
${SHEET_NAME_15}
CHECKED - There shouldn't be any mistakes. Contact the engineer if you find any.
BOTTOM VIEW
${SHEET_NAME_14}
${SHEET_NAME_21}
${SHEET_NAME_17}
${SHEET_NAME_18}
Date: ${RELEASE_DATE}
${SHEET_NAME_7}
${BOARD_NAME}
NOTES
${SHEET_NAME_1}
${SHEET_NAME_9}
${SHEET_NAME_29}
${SHEET_NAME_16}
${SHEET_NAME_3}
${SHEET_NAME_19}
Comment
TOP VIEW
${SHEET_NAME_10}

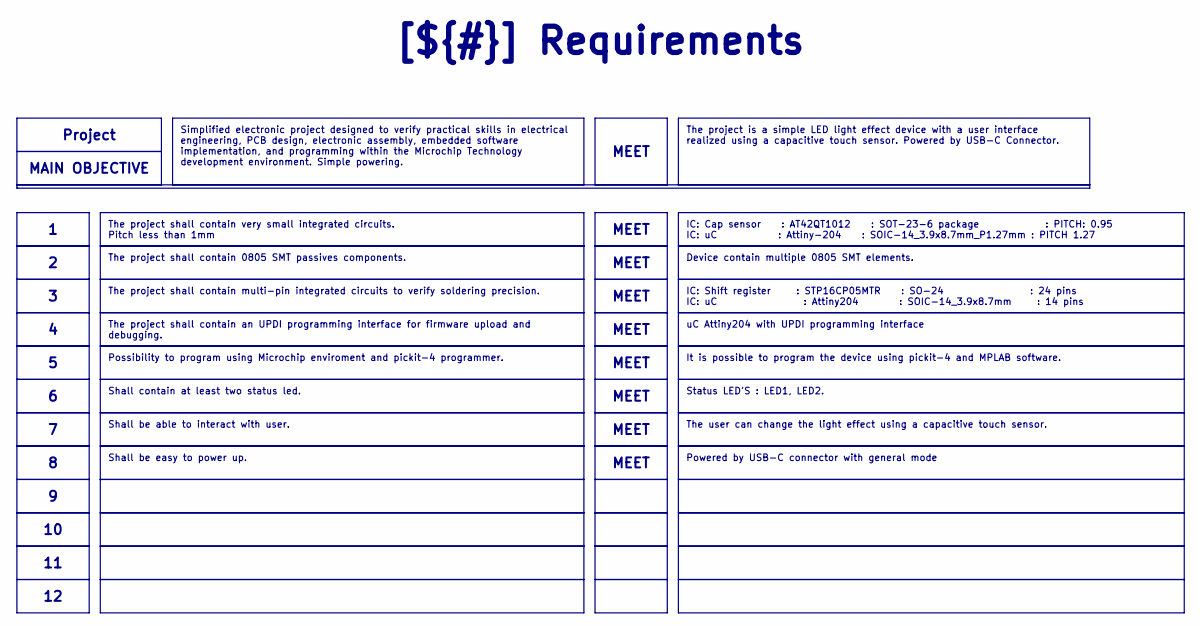
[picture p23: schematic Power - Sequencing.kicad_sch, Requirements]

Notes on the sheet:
Shall be able to interact with user.
IC: Cap sensor : AT42QT1012 : SOT-23-6 package : PITCH: 0.95 IC: uC : Attiny-204 : SOIC-14_3.9x8.7mm_P1.27mm : PITCH 1.27
Project
Shall be easy to power up.
Simplified electronic project designed to verify practical skills in electrical engineering, PCB design, electronic assembly, embedded software implementation, and programming within the Microchip Technology development environment. Simple powering.
MEET
Status LED'S : LED1, LED2.
uC Attiny204 with UPDI programming interface
The project shall contain 0805 SMT passives components.
Device contain multiple 0805 SMT elements.
The project shall contain very small integrated circuits. Pitch less than 1mm
[${#}] ${TITLE}
The project is a simple LED light effect device with a user interface realized using a capacitive touch sensor. Powered by USB-C Connector.
The user can change the light effect using a capacitive touch sensor.
IC: Shift register : STP16CP05MTR : SO-24 : 24 pins IC: uC : Attiny204 : SOIC-14_3.9x8.7mm : 14 pins
MAIN OBJECTIVE
Powered by USB-C connector with general mode
The project shall contain an UPDI programming interface for firmware upload and debugging.
Shall contain at least two status led.
It is possible to program the device using pickit-4 and MPLAB software.
Possibility to program using Microchip enviroment and pickit-4 programmer.
The project shall contain multi-pin integrated circuits to verify soldering precision.

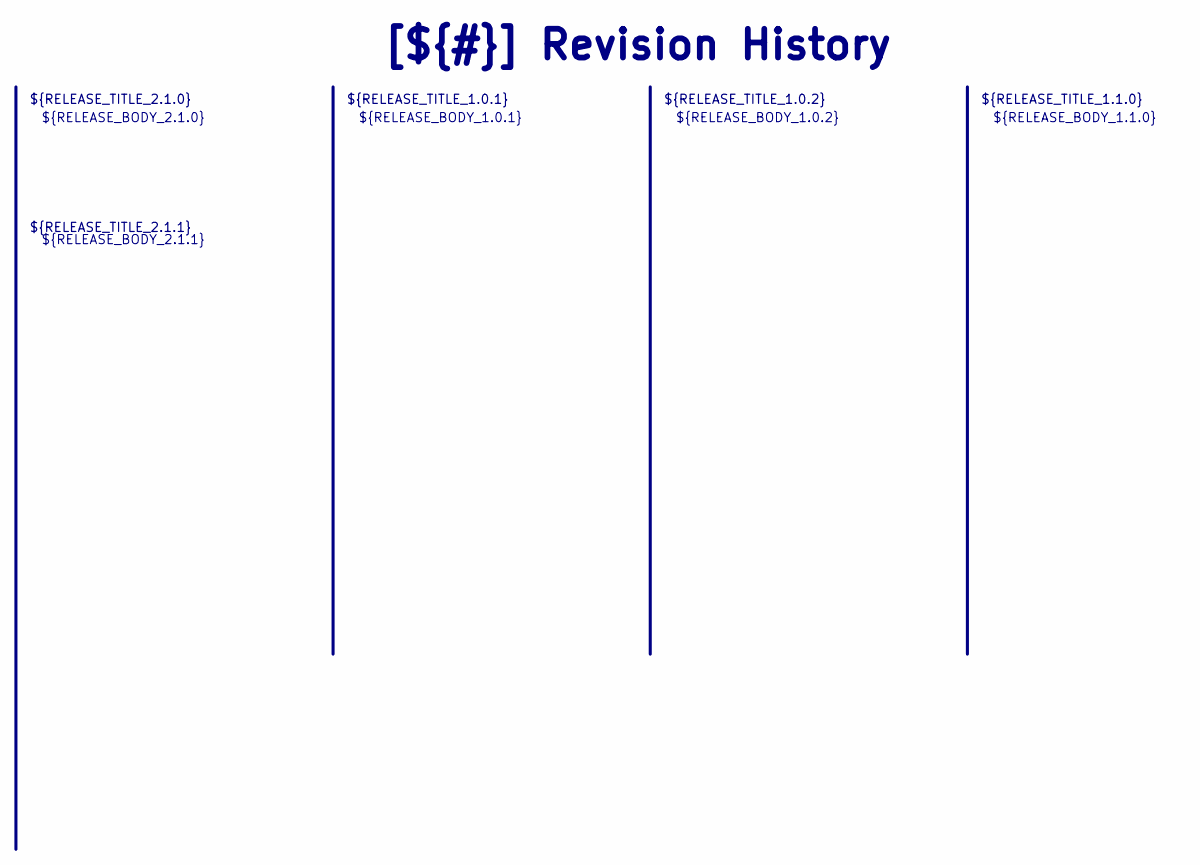
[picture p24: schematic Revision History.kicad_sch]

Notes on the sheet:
${RELEASE_TITLE_2.1.1}
${RELEASE_BODY_1.1.0}
[${#}] ${TITLE}
${RELEASE_BODY_2.1.0}
${RELEASE_TITLE_1.0.2}
${RELEASE_BODY_2.1.1}
${RELEASE_BODY_1.0.2}
${RELEASE_BODY_1.0.1}
${RELEASE_TITLE_2.1.0}
${RELEASE_TITLE_1.0.1}
${RELEASE_TITLE_1.1.0}

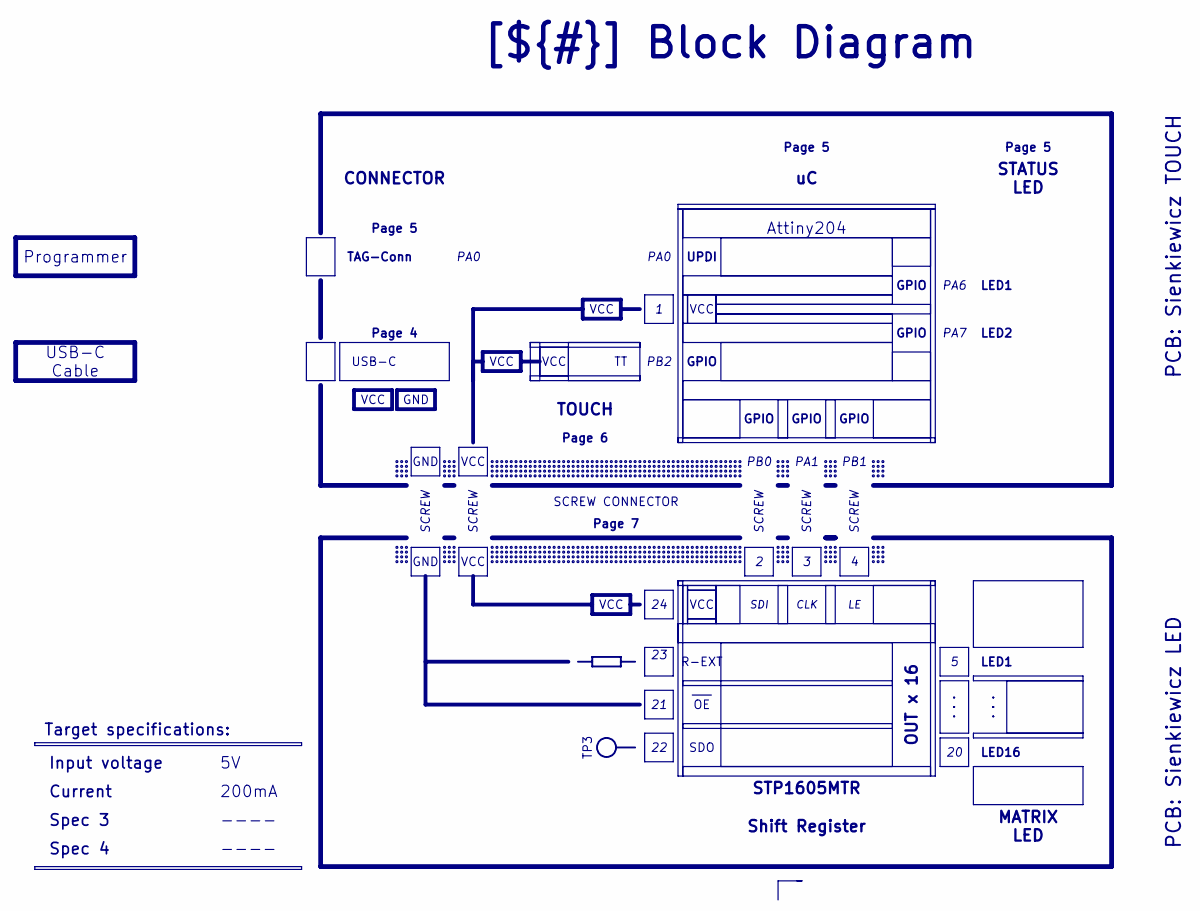
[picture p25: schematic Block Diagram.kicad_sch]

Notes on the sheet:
PCB: Sienkiewicz TOUCH
PCB: Sienkiewicz LED
MATRIX LED
VCC
LED1
Current
SDO
PB0
USB-C
GND
Input voltage
Page 5
PA1
TOUCH
CLK
PA7
200mA
SCREW
Spec 4
SDI
UPDI
SCREW CONNECTOR
PA6
Programmer
GPIO
Spec 3
Page 6
LED16
TP3
USB-C Cable
PA0
Page 7
Shift Register
STP1605MTR
Page 4
R-EXT
Attiny204
PB2
[${#}] ${TITLE}
OUT x 16

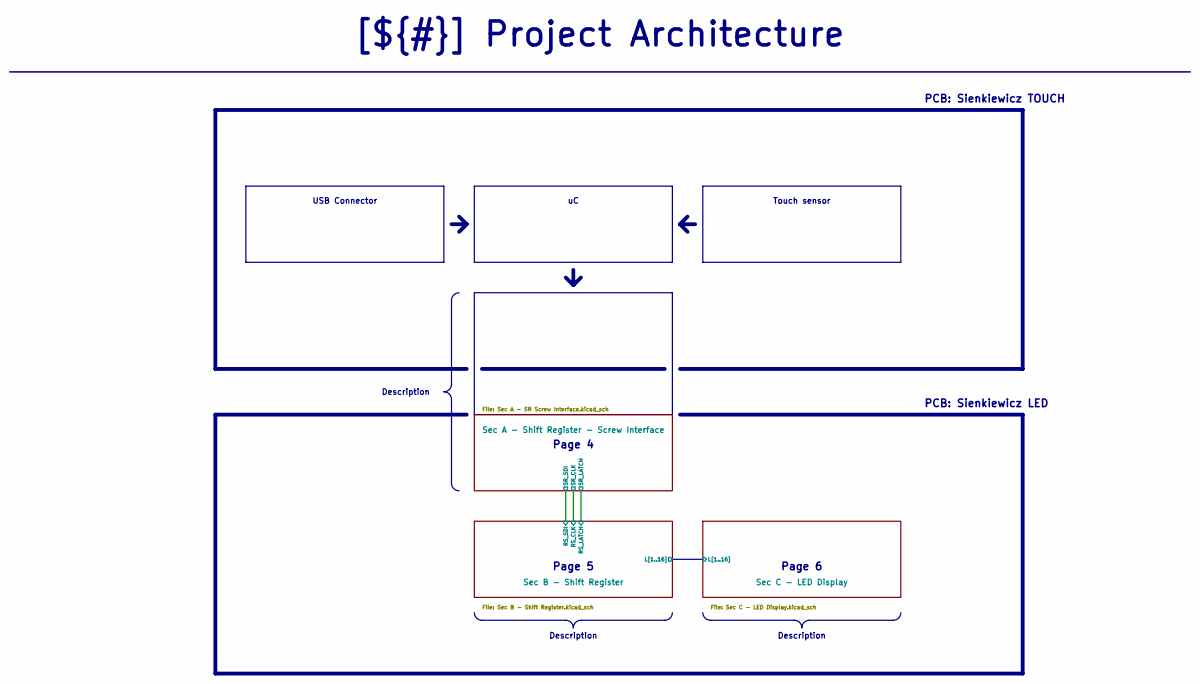
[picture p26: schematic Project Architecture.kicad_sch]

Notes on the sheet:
PCB: Sienkiewicz LED
Page 4
PCB: Sienkiewicz TOUCH
Touch sensor
USB Connector
Page 6
Page 5
Description
[${#}] ${TITLE}

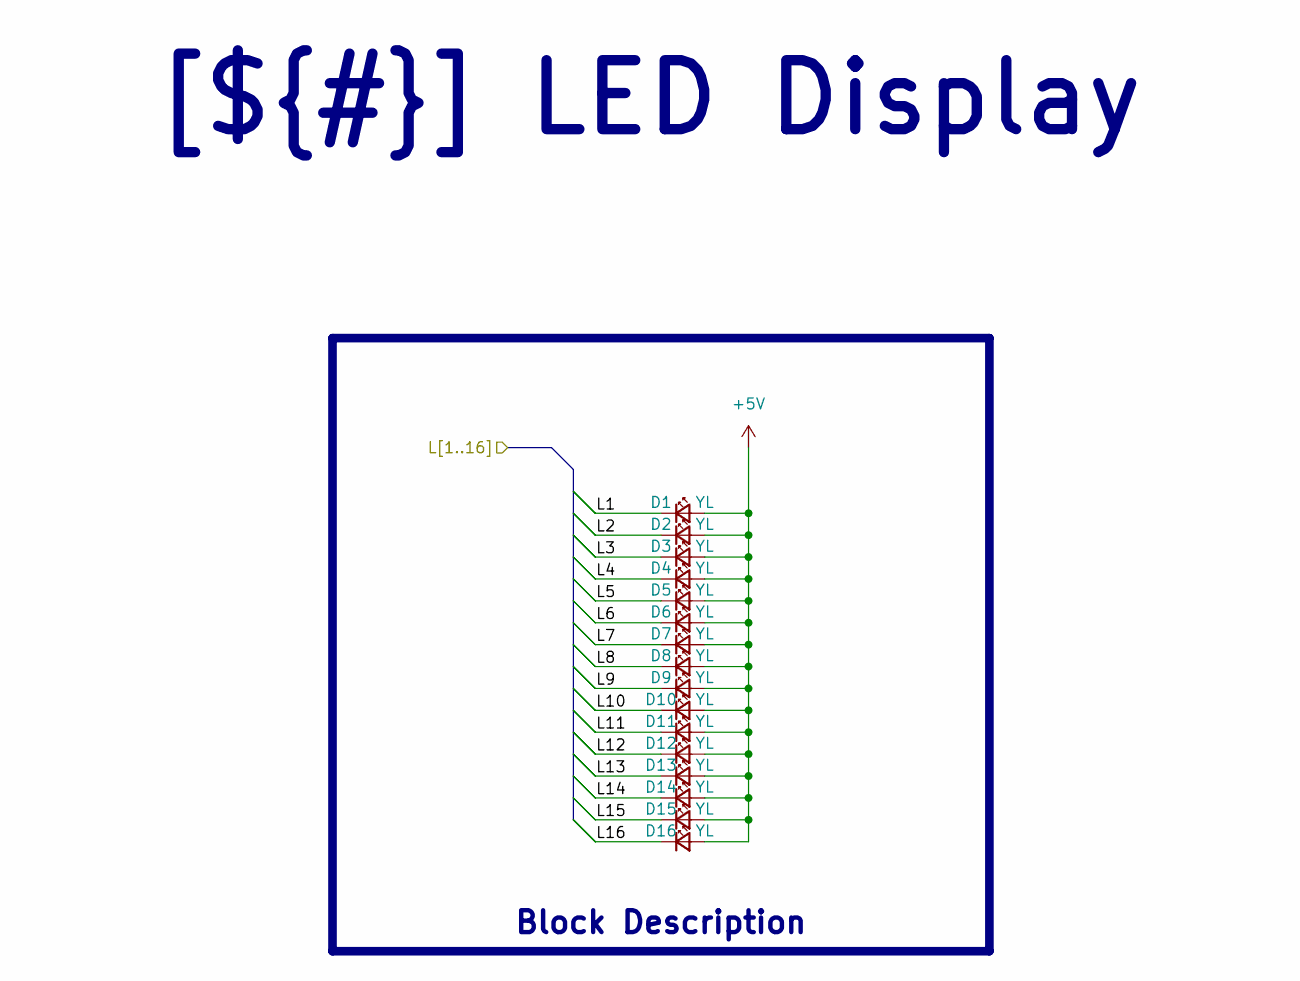
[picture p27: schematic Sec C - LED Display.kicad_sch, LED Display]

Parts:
D1, D2, D3, D4, D5, D6, D7, D8, D9, D10, D11, D12, D13, D14, D15, D16: YL; LED_1206_3216Metric

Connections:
+5V: D1.2 (A), D2.2 (A), D3.2 (A), D4.2 (A), D5.2 (A), D6.2 (A), D7.2 (A), D8.2 (A), D9.2 (A), D10.2 (A), D11.2 (A), D12.2 (A), D13.2 (A), D14.2 (A), D15.2 (A), D16.2 (A); also elsewhere on the board
/Project Architecture/Sec B - Shift Register/L1: D1.1 (K); also elsewhere on the board
/Project Architecture/Sec B - Shift Register/L2: D2.1 (K); also elsewhere on the board
/Project Architecture/Sec B - Shift Register/L3: D3.1 (K); also elsewhere on the board
/Project Architecture/Sec B - Shift Register/L4: D4.1 (K); also elsewhere on the board
/Project Architecture/Sec B - Shift Register/L5: D5.1 (K); also elsewhere on the board
/Project Architecture/Sec B - Shift Register/L6: D6.1 (K); also elsewhere on the board
/Project Architecture/Sec B - Shift Register/L7: D7.1 (K); also elsewhere on the board
/Project Architecture/Sec B - Shift Register/L8: D8.1 (K); also elsewhere on the board
/Project Architecture/Sec B - Shift Register/L9: D9.1 (K); also elsewhere on the board
/Project Architecture/Sec B - Shift Register/L10: D10.1 (K); also elsewhere on the board
/Project Architecture/Sec B - Shift Register/L11: D11.1 (K); also elsewhere on the board
/Project Architecture/Sec B - Shift Register/L12: D12.1 (K); also elsewhere on the board
/Project Architecture/Sec B - Shift Register/L13: D13.1 (K); also elsewhere on the board
/Project Architecture/Sec B - Shift Register/L14: D14.1 (K); also elsewhere on the board
/Project Architecture/Sec B - Shift Register/L15: D15.1 (K); also elsewhere on the board
/Project Architecture/Sec B - Shift Register/L16: D16.1 (K); also elsewhere on the board

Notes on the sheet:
[${#}] ${TITLE}
Block Description

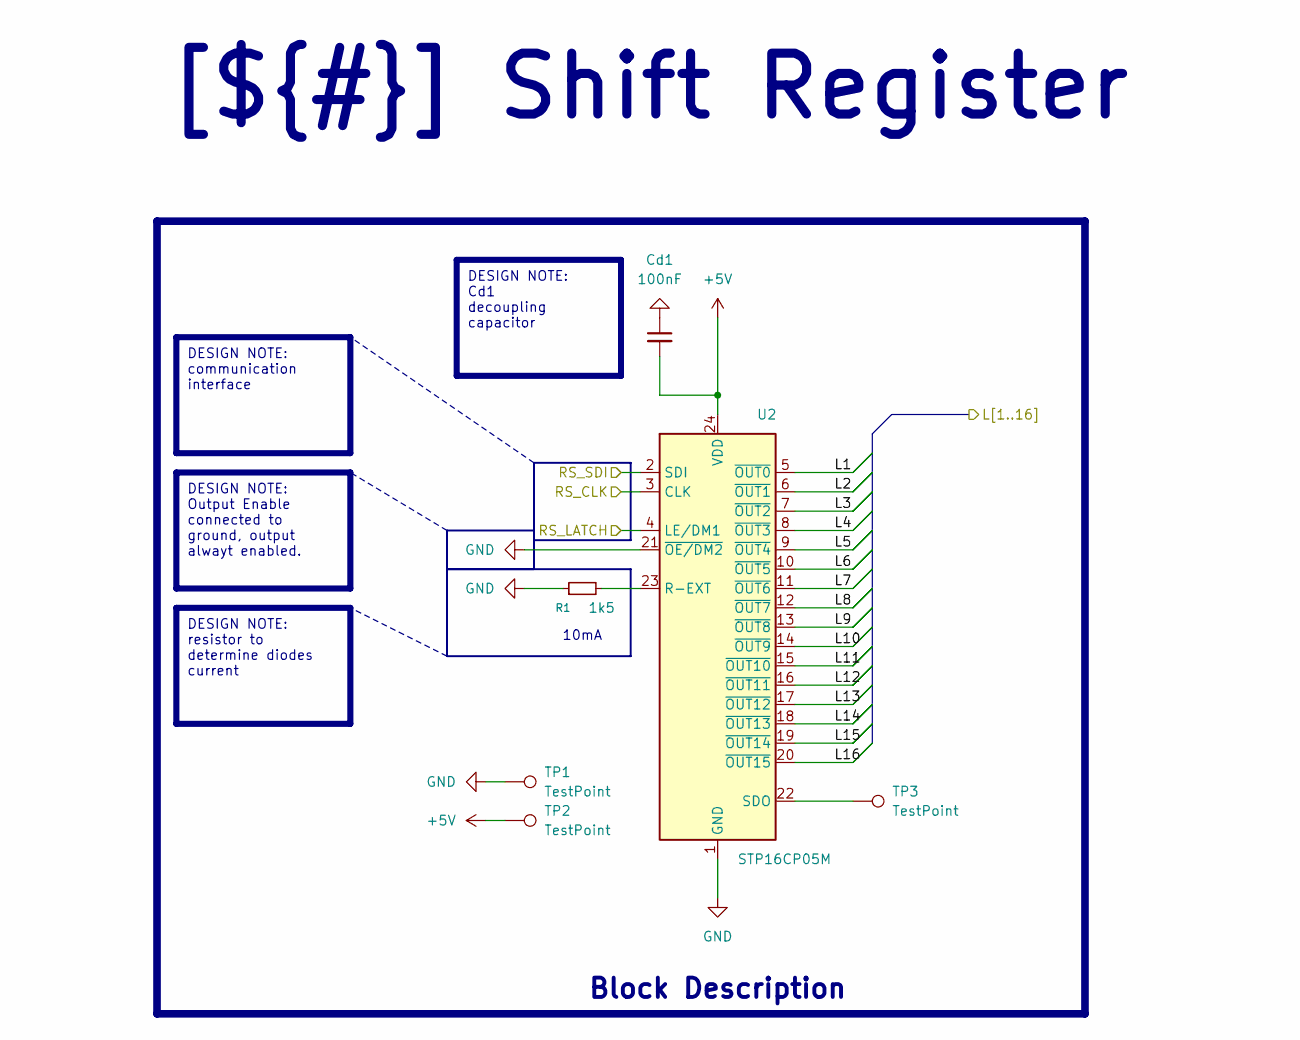
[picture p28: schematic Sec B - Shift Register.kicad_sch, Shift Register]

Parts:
Cd1: 100nF; C_1210_3225Metric
R1: 1k5; R_1206_3216Metric
TP1, TP2, TP3: TestPoint; TestPoint_Pad_D1.0mm
U2: STP16CP05M; SOIC-24W_7.5x15.4mm_P1.27mm

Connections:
+5V: Cd1.2, TP2.1, U2.24 (VDD); also elsewhere on the board
/Project Architecture/Sec A - Shift Register - Screw Interface/SR_CLK: U2.3 (CLK); also elsewhere on the board
/Project Architecture/Sec A - Shift Register - Screw Interface/SR_LATCH: U2.4 (LE/DM1); also elsewhere on the board
/Project Architecture/Sec A - Shift Register - Screw Interface/SR_SDI: U2.2 (SDI); also elsewhere on the board
/Project Architecture/Sec B - Shift Register/L1: U2.5 (~OUT0); also elsewhere on the board
/Project Architecture/Sec B - Shift Register/L2: U2.6 (~OUT1); also elsewhere on the board
/Project Architecture/Sec B - Shift Register/L3: U2.7 (~OUT2); also elsewhere on the board
/Project Architecture/Sec B - Shift Register/L4: U2.8 (~OUT3); also elsewhere on the board
/Project Architecture/Sec B - Shift Register/L5: U2.9 (~OUT4); also elsewhere on the board
/Project Architecture/Sec B - Shift Register/L6: U2.10 (~OUT5); also elsewhere on the board
/Project Architecture/Sec B - Shift Register/L7: U2.11 (~OUT6); also elsewhere on the board
/Project Architecture/Sec B - Shift Register/L8: U2.12 (~OUT7); also elsewhere on the board
/Project Architecture/Sec B - Shift Register/L9: U2.13 (~OUT8); also elsewhere on the board
/Project Architecture/Sec B - Shift Register/L10: U2.14 (~OUT9); also elsewhere on the board
/Project Architecture/Sec B - Shift Register/L11: U2.15 (~OUT10); also elsewhere on the board
/Project Architecture/Sec B - Shift Register/L12: U2.16 (~OUT11); also elsewhere on the board
/Project Architecture/Sec B - Shift Register/L13: U2.17 (~OUT12); also elsewhere on the board
/Project Architecture/Sec B - Shift Register/L14: U2.18 (~OUT13); also elsewhere on the board
/Project Architecture/Sec B - Shift Register/L15: U2.19 (~OUT14); also elsewhere on the board
/Project Architecture/Sec B - Shift Register/L16: U2.20 (~OUT15); also elsewhere on the board
GND: Cd1.1, R1.1, TP1.1, U2.1 (GND), U2.21 (~OE/DM2); also elsewhere on the board
unnamed: R1.2, U2.23 (R-EXT)
unnamed: TP3.1, U2.22 (SDO)

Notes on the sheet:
10mA
DESIGN NOTE: Output Enable connected to ground, output alwayt enabled.
[${#}] ${TITLE}
Block Description
DESIGN NOTE: Cd1 decoupling capacitor
DESIGN NOTE: communication interface
DESIGN NOTE: resistor to determine diodes current

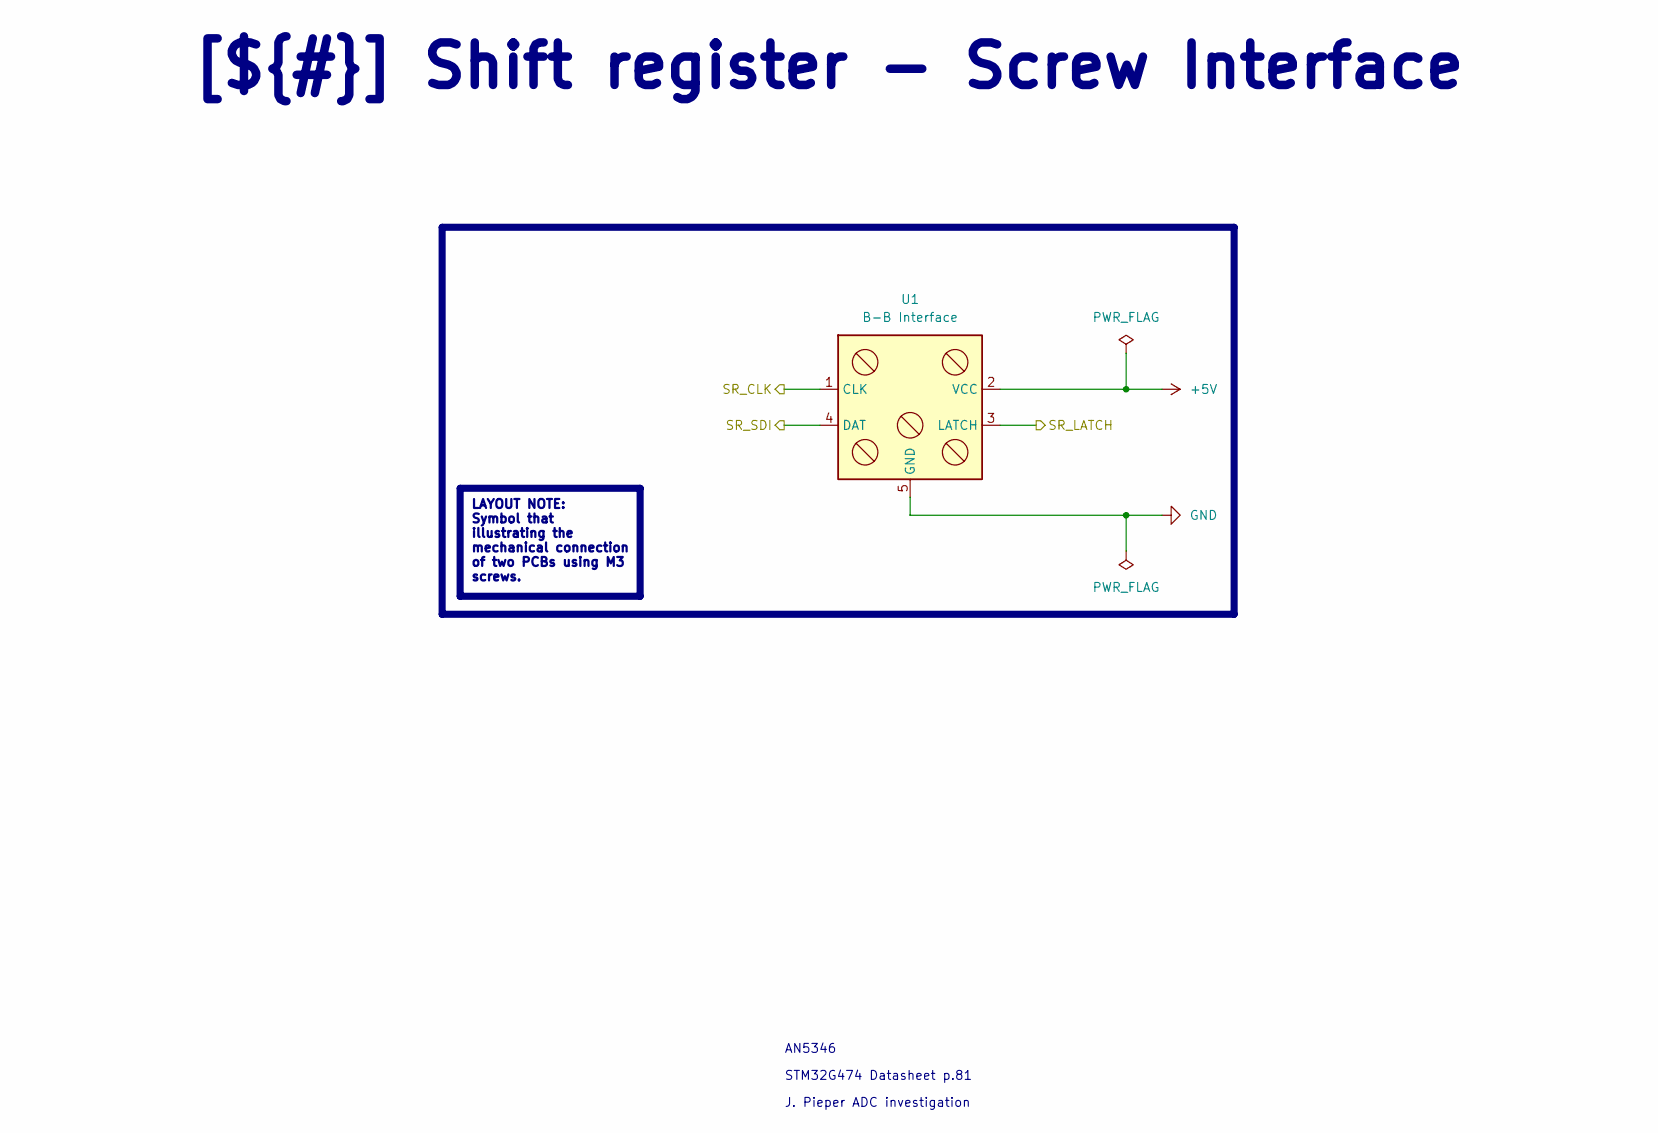
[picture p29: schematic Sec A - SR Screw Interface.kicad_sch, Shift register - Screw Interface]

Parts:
U1: B-B Interface; Sienkiewicz

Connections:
+5V: U1.2 (VCC); also elsewhere on the board
/Project Architecture/Sec A - Shift Register - Screw Interface/SR_CLK: U1.1 (CLK); also elsewhere on the board
/Project Architecture/Sec A - Shift Register - Screw Interface/SR_LATCH: U1.3 (LATCH); also elsewhere on the board
/Project Architecture/Sec A - Shift Register - Screw Interface/SR_SDI: U1.4 (DAT); also elsewhere on the board
GND: U1.5 (GND); also elsewhere on the board

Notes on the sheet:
J. Pieper ADC investigation
STM32G474 Datasheet p.81
AN5346
LAYOUT NOTE: Symbol that illustrating the mechanical connection of two PCBs using M3 screws.
[${#}] ${TITLE}

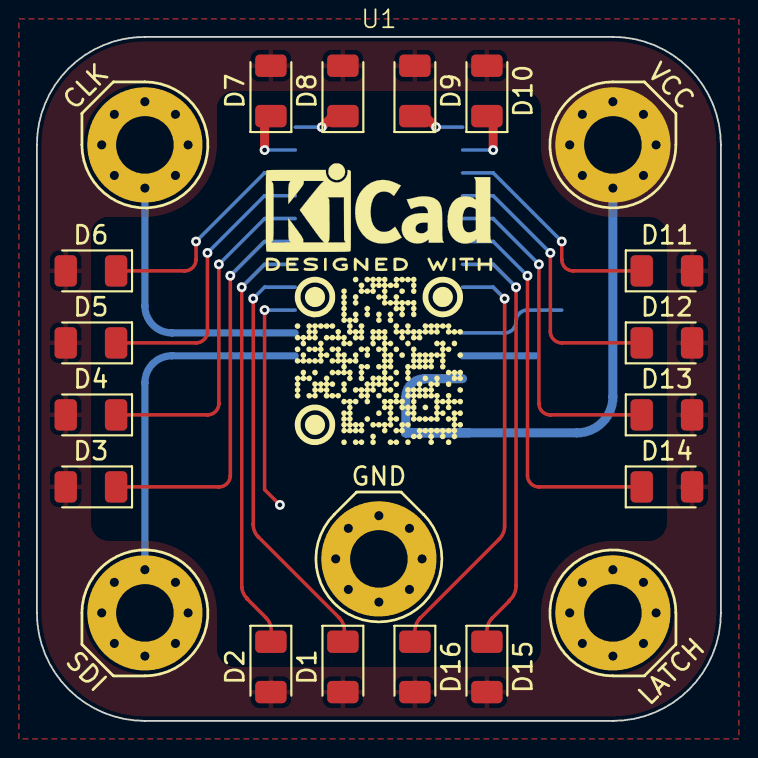
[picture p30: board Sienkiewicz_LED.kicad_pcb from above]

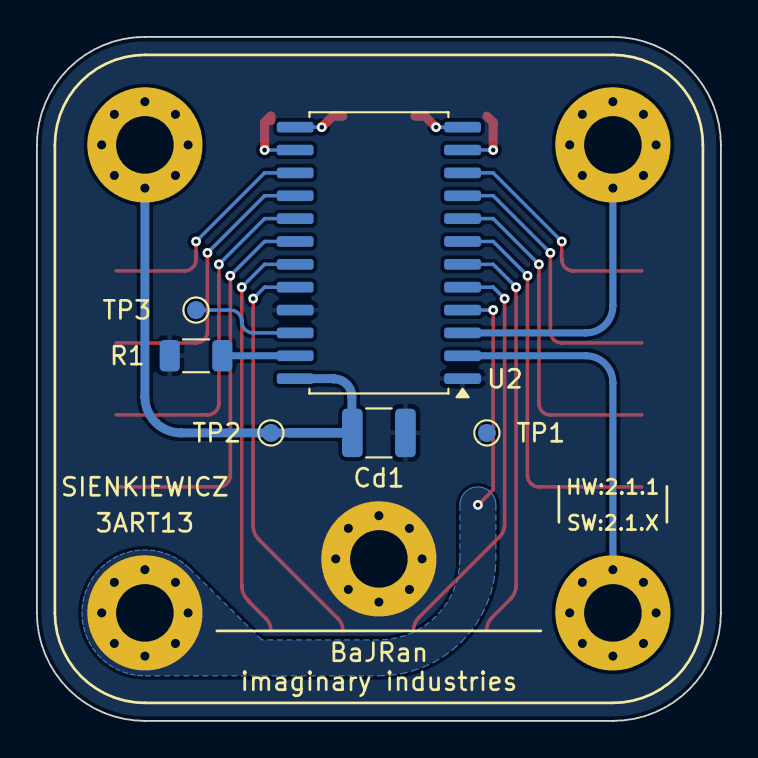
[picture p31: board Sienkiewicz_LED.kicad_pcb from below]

Board: 2 copper layers, 38.0 x 38.0 mm, 23 parts (6 on the bottom side), 23 nets.

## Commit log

2026-04-30 Update Outputs
    [Sienkiewicz_LED-bom.csv]
2026-04-30 [sch] first release of the schematic
    [Block Diagram.kicad_sch, Power - Sequencing.kicad_sch, Project Architecture.kicad_sch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]
2026-05-02 preliminary pcb version
    [Sec A - SR Screw Interface.kicad_sch, Sec B - Shift Register.kicad_sch, Sec C - LED Display.kicad_sch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]
2026-05-02 testpoints F.Fab descriptions removed
    [Sienkiewicz_LED.kicad_pcb]
2026-05-02 F.Silkscreen update
    [Sienkiewicz_LED.kicad_pcb]
2026-05-02 silkscreen test
    [Sienkiewicz_LED.kicad_pcb]
2026-05-02 blender is wrongly rendering the images
    [Sienkiewicz_LED.kicad_pcb]
2026-05-02 testpoints silkscreen tests
    [Sienkiewicz_LED.kicad_pcb]
2026-05-02 blender rendering silkscreen solved
    [Sienkiewicz_LED.kicad_pcb]
2026-05-02 checked version
    [Revision History.kicad_sch, Sec A - SR Screw Interface.kicad_sch, Sec B - Shift Register.kicad_sch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]
2026-05-02 Update Outputs (release)
    [Sienkiewicz_LED-B_Cu (Sig, PWR).gbr, Sienkiewicz_LED-B_Mask.gbr, Sienkiewicz_LED-B_Paste.gbr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]
2026-05-21 documentation update / block diagram
    [Block Diagram.kicad_sch, Project Architecture.kicad_sch, Sec C - LED Display.kicad_sch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]
2026-05-21 changed track to bus
    [Project Architecture.kicad_sch]
2026-05-21 documentation update / release 2.1.1 prep
    [Power - Sequencing.kicad_sch, Project Architecture.kicad_sch, Revision History.kicad_sch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]
2026-05-21 block diagram update
    [Block Diagram.kicad_sch]
2026-05-21 silkcreen version bump to 2.1.1
    [Sienkiewicz_LED.kicad_pcb]
2026-05-21 pcb silkscreen version fix
    [Sienkiewicz_LED.kicad_pcb]
2026-06-08 readme.md update
    [Sienkiewicz_LED.kicad_pcb]
2026-06-11 schematic update - block diagram pictures added
    [Block Diagram.kicad_sch]
2026-06-11 fix naming CLK, SDI
    [Sec A - SR Screw Interface.kicad_sch, Sienkiewicz_LED.kicad_pcb]
